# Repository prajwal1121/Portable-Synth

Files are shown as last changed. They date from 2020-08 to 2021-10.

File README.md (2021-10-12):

# Portable Synth
### An OP-1 inspired portable groovebox based around Teensy 4.1
Built using the awesome Teensy Audio Library
 
This project is still in progress, and will be for a while. Check back often for updates and bug fixes

**Current Status (1/13/2021)::white_check_mark:**

**Latest Updates (2/3/2021):** This code is outgrowing the Arduino IDE and I'm finally making the switch to VSCode and Platformio! This means the code will now and henceforth be organized in a more traditional C++ project structure rather than an awkward collections of .ino files. More importantly, the latest groovebox firmware has been reorganized into classes and multiple files in an effort to make it more modulualr and OOP-y. See README in Software folder for more information.

##### Check out the following links for development updates and more information about how to use the project files above
* Part 1 (Version 1): http://praj.tech/portfolio/portable-synth-v1-prototype/
* Part 2 (Version 1): http://praj.tech/portfolio/portable-synth-concept-design/
* Part 3 (Version 2): http://praj.tech/portfolio/porable-synth-hardware-upgrade/
* Part 4 (Version 2): http://praj.tech/portfolio/portable-synth-v2/

##### Or watch the demo videos here
###### V2
* Audio Recording and FM Radio: https://youtu.be/2ahzlKvuJ6E
* Build: https://youtu.be/Mdk-aUEtNno
* Sample Packs and Step Sequencer: https://youtu.be/XyqohSevqoo
* V2 Hardware and Synth with Mod Matrix: https://youtu.be/yj9AeDa9qw8

###### V1
* Endless Sequencer: https://youtu.be/U5Ci-TUZ0MY
* Recording and Sampling: https://youtu.be/KuPWz8McP5k
* Subtractive Synthesizer: https://youtu.be/QcZ3WIZ24l4

#### V2 - November 2020
Device Image

#### V1 Prototype - August 2020
Device Image

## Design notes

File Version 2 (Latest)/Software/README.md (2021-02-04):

## Project Code Files
The latest firmware can be found in the Groovebox_Platformio folder (a Platformio Project). Import it using Platformio into your editor of choice (I use VSCode). 

**A note for Platformio users:** Delete SDFat.h from *C:\Users\USERNAME\\.platformio\packages\framework-arduinoteensy\libraries\SD\utility* and instead install the latest version of the SDFat library through Platformio. This fixes a lot of problems. 

## Compiled Hex
If you don't actually want to see any of the code, just download the corresponding hex file, open it using Teensy Loader, and press the button on your Teensy to upload it!

## Older Code
Older code can be found in the Arduino Projects folder. These are all .ion files and can easily be opened and edited using the Arduino IDE.

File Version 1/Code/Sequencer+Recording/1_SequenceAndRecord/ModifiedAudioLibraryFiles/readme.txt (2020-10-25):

Replace the play_sd_raw.h and play_sd_raw.cpp files in your Teensy Audio Library directory with these files. 

They are identical except for the added ability to skip to a location in the audio file. See main sketch for usage example.

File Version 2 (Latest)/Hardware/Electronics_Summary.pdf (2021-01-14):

# V2.3 Electronics Summary

## Prajwal Tumkur Mahesh January 2020

# Schematics

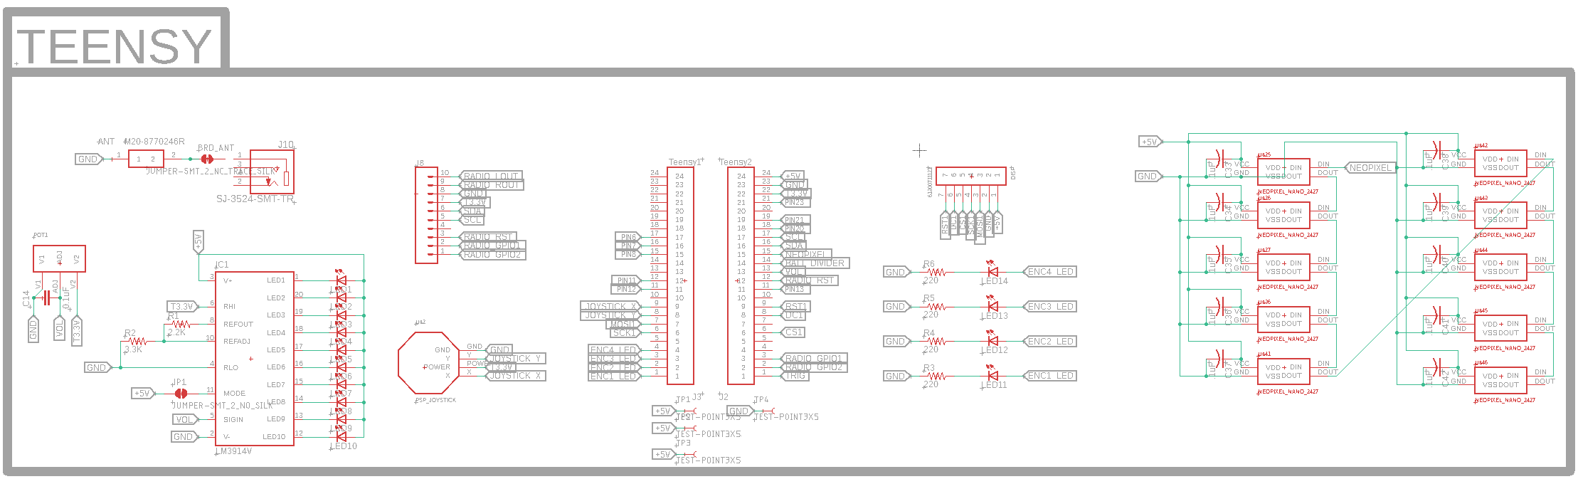
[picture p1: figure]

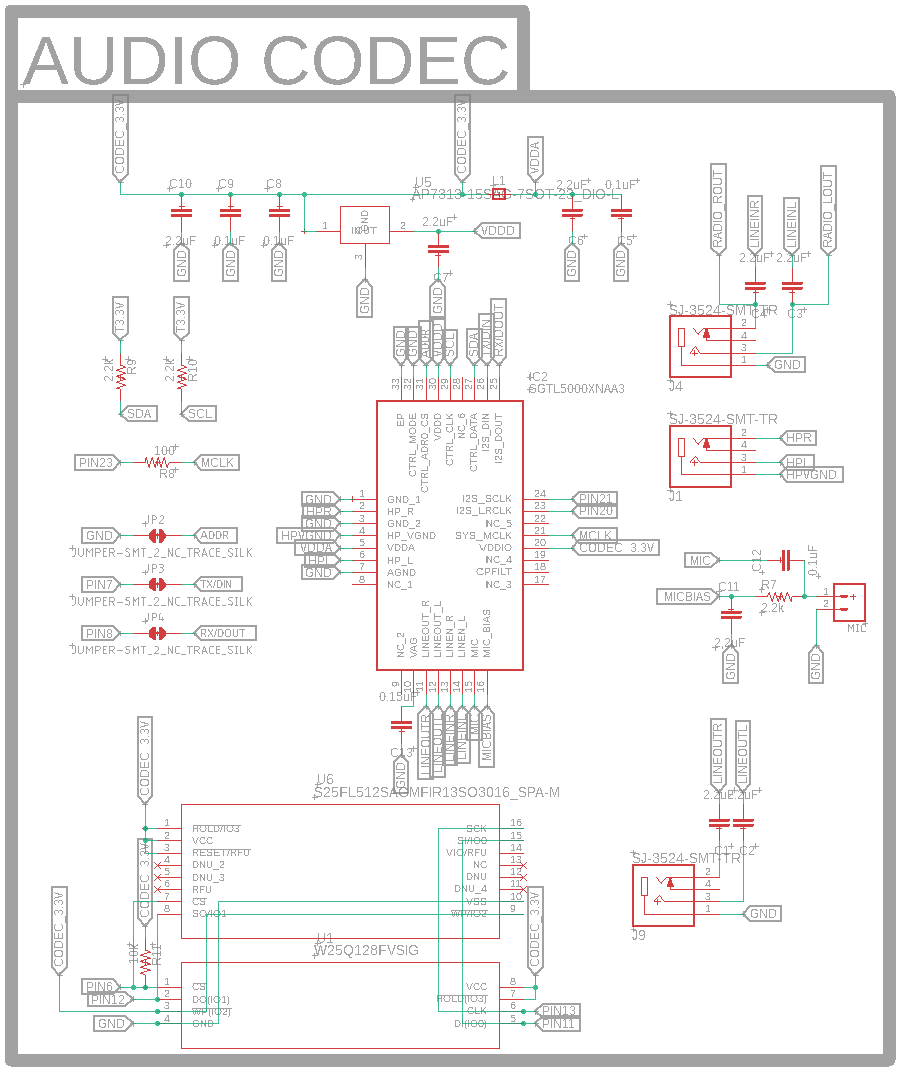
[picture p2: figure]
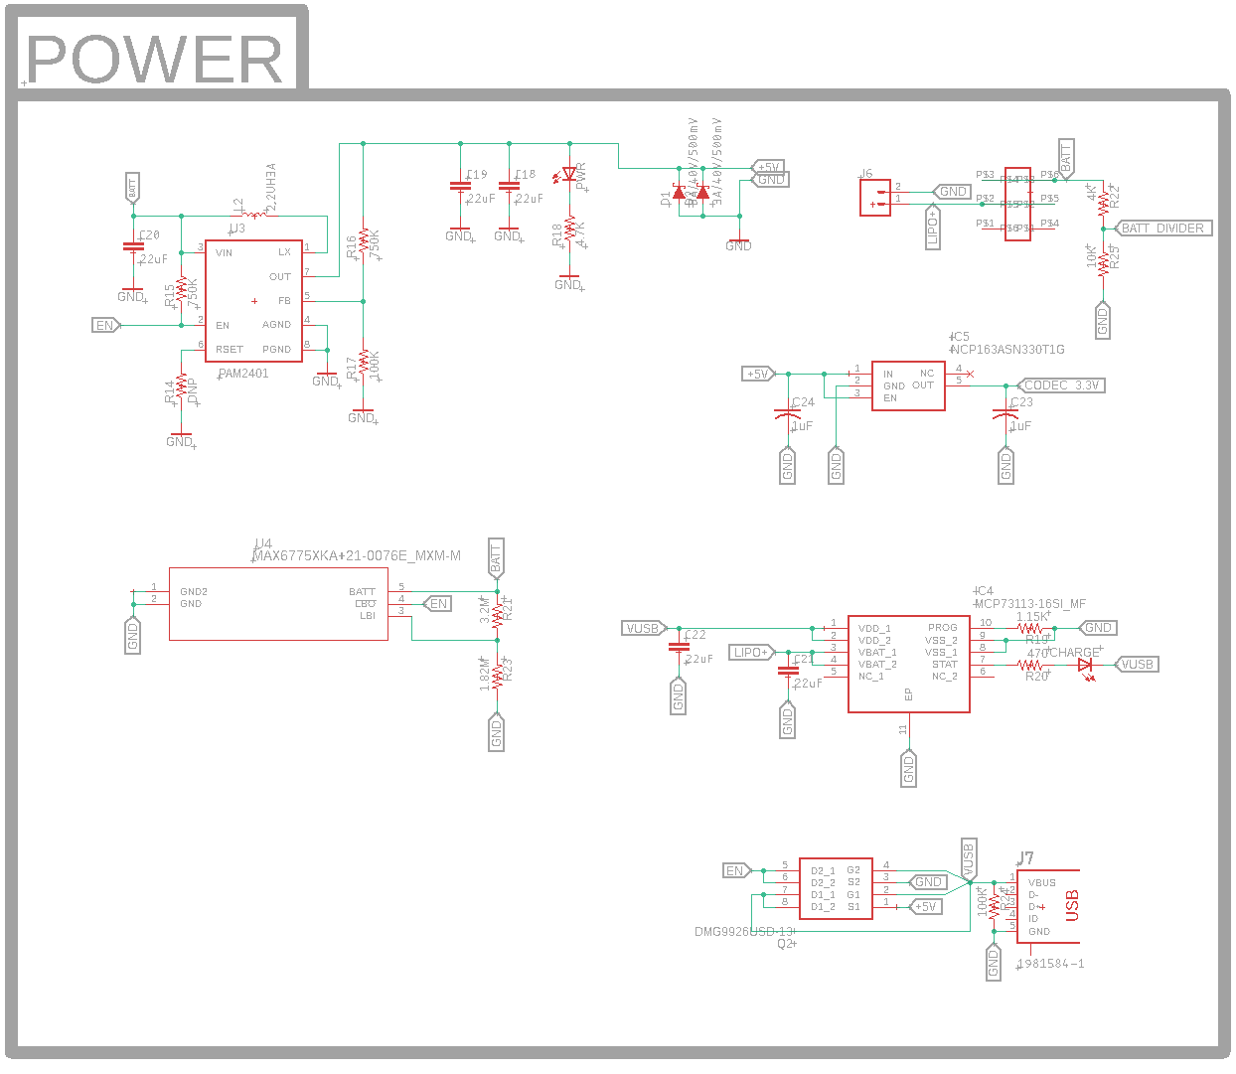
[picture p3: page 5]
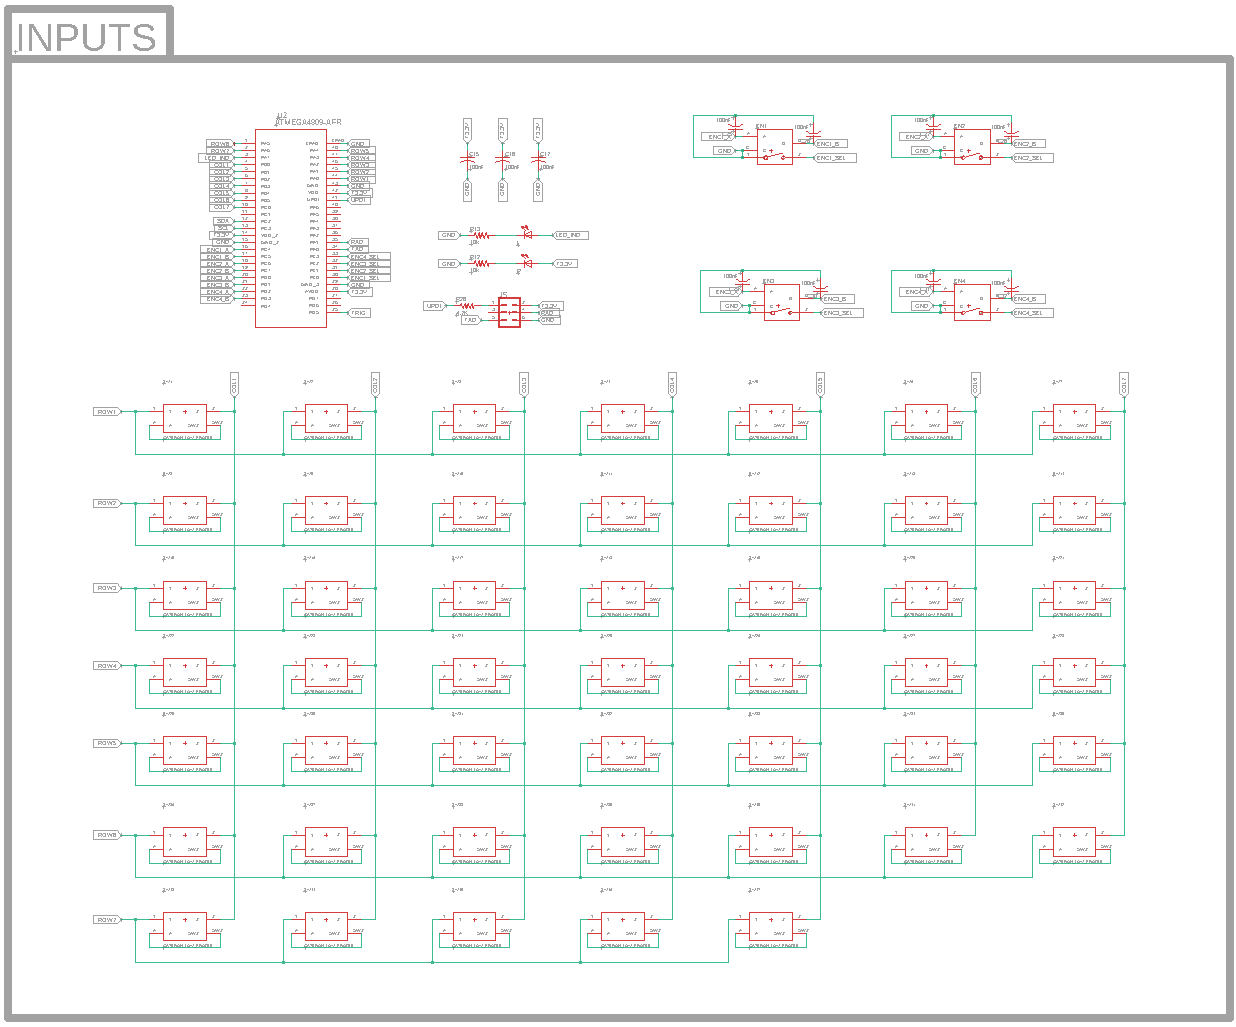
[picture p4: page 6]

# Board Layout

### FRONT:

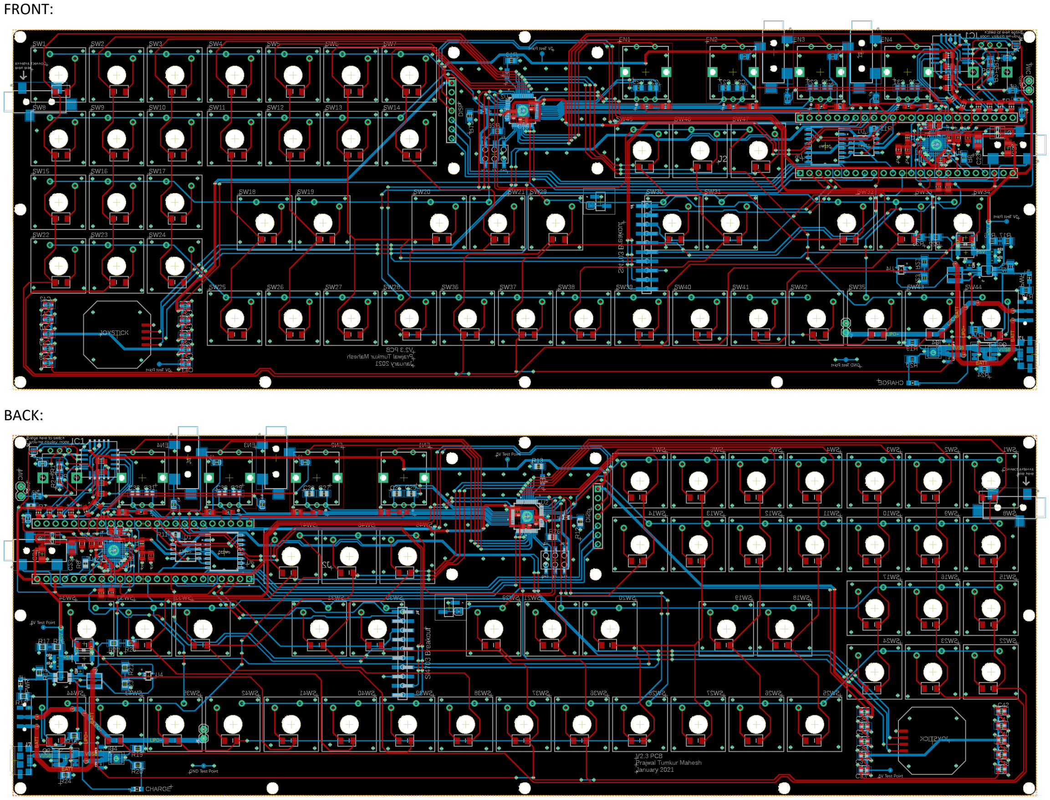
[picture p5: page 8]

### BACK:

# BOM

Manufacturer Part Number | Manufacturer | Digi-Key Part Number | Reference Designator | Quantity Unit Price Extended Price Description
CL21B225KPFNNNE | Samsung Electro-Mechanics | 1276-1188-1-ND | C1,C2,C3,C4,C6,C7,C10,C11 | 8 | 0.11 | $0.88 | CAP CER 2.2UF 10V X7R 0805
CL21B104KACNNNC | Samsung Electro-Mechanics | 1276-1099-1-ND | C5,C8,C9,C12,C14,C15,C16,C17,C25,C26,C27,C28,C29,
| | | C30,C31,C32,C33,C34,C35,C36,C37,C38,C39,C40,C41,C42 | 26 | 0.04 | $1.04 | CAP CER 0.1UF 25V X7R 0805
CL21B154KBFNNNG | Samsung Electro-Mechanics | 1276-6476-1-ND | C13 | 1 | 0.1 | $0.10 | CAP CER 0.15UF 50V X7R 0805
CL31B105KBHNFNE | Samsung Electro-Mechanics | 1276-3091-1-ND | C23,C24 | 2 | 0.15 | $0.30 | CAP CER 1UF 50V X7R 1206
3484 | Adafruit Industries LLC | 1528-2291-ND | | 1 | 4.95 | $4.95 | ADDRESS LED DISCRETE SERIAL RGB
LH R974-LP-1 | OSRAM Opto Semiconductors Inc. | 475-1415-1-ND | PWR,P,LED11 | 3 | 0.25 | $0.75 | LED RED DIFFUSED 0805 SMD
SML-LXT0805YW-TR | Lumex Opto/Components Inc. | 67-1554-1-ND | CHARGE,L,LED13 | 3 | 0.28 | $0.84 | LED YELLOW DIFFUSED SMD
QBLP631-IW | QT Brightek (QTB) | 1516-1085-1-ND | LED1,LED2,LED3,LED4,LED5,LED6,LED7,LED8,LED9,LED10 | 10 | 0.286 | $2.86 | LED WHITE 0805 SMD
LG R971-KN-1 | OSRAM Opto Semiconductors Inc. | 475-1410-1-ND | LED12 | 1 | 0.25 | $0.25 | LED GREEN DIFFUSED 0805 SMD
HSMR-C170 | Broadcom Limited | 516-1445-1-ND | LED14 | 1 | 0.8 | $0.80 | LED BLUE DIFFUSED CHIP SMD
PEC11R-4115F-S0018 | Bourns Inc. | PEC11R-4115F-S0018-ND | EN1,EN2,EN3,EN4 | 4 | 1.57 | $6.28 | ROTARY ENCODER MECHANICAL 18PPR
P0915N-FC15BR10K | TT Electronics/BI | 987-1649-ND | POT1 | 1 | 1.36 | $1.36 | POT 10K OHM 1/20W PLASTIC LINEAR
B340A-13-F | Diodes Incorporated | B340A-FDICT-ND | D1,D2 | 2 | 0.41 | $0.82 | DIODE SCHOTTKY 40V 3A SMA
SGTL5000XNAA3 | NXP USA Inc. | SGTL5000XNAA3-ND | IC2 | 1 | 3.37 | $3.37 | IC AUDIO CODEC STEREO 32-QFN
ATMEGA4809-AFR | Microchip Technology | ATMEGA4809-AFRCT-ND | U2 | 1 | 1.59 | $1.59 | IC MCU 8BIT 48KB FLASH 48TQFP
IFSC1515AHER2R2M01 | Vishay Dale | 541-1404-1-ND | L2 | 1 | 0.56 | $0.56 | FIXED IND 2.2UH 3A 45 MOHM SMD
742792040 | Würth Elektronik | 732-1620-1-ND | L1 | 1 | 0.22 | $0.22 | FERRITE BEAD 600 OHM 0805 1LN
RNCP0805FTD10K0 | Stackpole Electronics Inc | RNCP0805FTD10K0CT-ND | R11,R12,R13,R25 | 4 | 0.1 | $0.40 | RES 10K OHM 1% 1/4W 0805
ERA-6AEB104V | Panasonic Electronic Components | P100KDACT-ND | R17,R24 | 3 | 0.31 | $0.93 | RES 100K OHM 0.1% 1/8W 0805
ESR10EZPJ222 | Rohm Semiconductor | RHM2.2KKCT-ND | R1,R7,R9,R10 | 4 | 0.1 | $0.40 | RES SMD 2.2K OHM 5% 0.4W 0805
RC0805FR-07750KL | Yageo | 311-750KCRCT-ND | R15,R16 | 2 | 0.1 | $0.20 | RES SMD 750K OHM 1% 1/8W 0805
CRGCQ0805F3K3 | TE Connectivity Passive Product | A129755CT-ND | R2 | 2 | 0.1 | $0.20 | CRGCQ 0805 3K3 1%
RC0805JR-074K7L | Yageo | 311-4.7KARCT-ND | R18,R26 | 2 | 0.1 | $0.20 | RES SMD 4.7K OHM 5% 1/8W 0805
RC0805FR-071K15L | Yageo | 311-1.15KCRCT-ND | R19 | 1 | 0.1 | $0.10 | RES SMD 1.15K OHM 1% 1/8W 0805
CRCW08054K00FKTA | Vishay Dale | 541-CRCW08054K00FKTACT-ND | R22 | 1 | 0.13 | $0.13 | RES SMD 4K OHM 1% 1/8W 0805
JS202011JAQN | C&K | CKN10722CT-ND | | 1 | 0.58 | $0.58 | SWITCH SLIDE DPDT 300MA 6V
W25Q128JVSIQ TR | Winbond Electronics | W25Q128JVSIQCT-ND | U1 | 1 | 1.42 | $1.42 | IC FLASH 128MBIT SPI/QUAD 8SOIC
PAM2401SCADJ | Diodes Incorporated | PAM2401SCADJDICT-ND | U3 | 1 | 0.99 | $0.99 | IC REG BOOST ADJUSTABLE 1A 8MSOP
AP7313-15SAG-7 | Diodes Incorporated | AP7313-15SAG-7DICT-ND | U5 | 1 | 0.39 | $0.39 | IC REG LINEAR 1.5V 150MA SOT23-3
MCP73113-16SI/MF | Microchip Technology | MCP73113-16SI/MF-ND | IC4 | 1 | 1.12 | $1.12 | IC BATT CONTRL LI-ION 1CEL 10DFN
NCP163ASN330T1G | ON Semiconductor | NCP163ASN330T1GOSCT-ND | IC5 | 1 | 0.49 | $0.49 | LDO REG ULTRA-LOW NOISE & HIGH P
SJ-3524-SMT-TR | CUI Devices | CP-3524SJCT-ND | | 4 | 0.95 | $3.80 | CONN JACK STEREO 3.5MM SMD R/A
10118192-0001LF | Amphenol ICC (FCI) | 609-4613-1-ND | | 1 | 0.48 | $0.48 | CONN RCPT USB2.0 MICRO B SMD R/A
10129380-910001ALF | Amphenol ICC (FCI) | 609-10129380-910001ALFCT-ND | | 1 | 0.26 | $0.26 | CONN HEADER SMD 10POS 2.54MM
DM3CS-SF | Hirose Electric Co Ltd | HR1972CT-ND | | 1 | 1.43 | $1.43 | CONN MICRO SD CARD HINGED TYPE
MAX6775XKB+T | Maxim Integrated | MAX6775XKB+TCT-ND | U4 | 1 | 2.18 | $2.18 | IC BATT MON MULTI-CHEM 1C SC70-5
POM-5046P-C3310-R | PUI Audio, Inc. | 668-1677-ND | MIC | 1 | 1.69 | $1.69 | MIC COND ANALOG OMNI -46DB 6MM D
LL4148 | ON Semiconductor | LL4148FSCT-ND | | 50 | 0.068 | $3.40 | DIODE GEN PURP 100V 200MA SOD80
RC0805FR-073M16L | Yageo | 311-3.16MCRCT-ND | R21 | 1 | 0.1 | $0.10 | RES SMD 3.16M OHM 1% 1/8W 0805
CRCW08051M82FKEA | Vishay Dale | 541-1.82MCCT-ND | R23 | 1 | 0.1 | $0.10 | RES SMD 1.82M OHM 1% 1/8W 0805
LM3914VX/NOPB | Texas Instruments | LM3914VX/NOPBCT-ND | IC1 | 1 | 3.71 | $3.71 | IC DRVR DOT/BAR DISPLAY 20PLCC
CRGCQ0805F220R | TE Connectivity Passive Product | A129741CT-ND | R3,R4,R5,R6 | 10 | 0.044 | $0.44 | CRGCQ 0805 220R 1%
CRGCQ0805J100R | TE Connectivity Passive Product | A130128CT-ND | R8 | 1 | 0.1 | $0.10 | CRGCQ 0805 100R 5%
CRGCQ0805F470R | TE Connectivity Passive Product | A129745CT-ND | R20 | 1 | 0.1 | $0.10 | CRGCQ 0805 470R 1%
CL21A226MQQNNNE | Samsung Electro-Mechanics | 1276-1100-1-ND | C18,C19,C20,C21,C22 | 5 | 0.14 | $0.70 | CAP CER 22UF 6.3V X5R 0805
444 | Adafruit Industries LLC | 1528-444-ND | JOYSTICK | 1 | 3.5 | $3.50 | PSP 2-AXIS ANALOG THUMB JOYSTICK
S25FL512SAGMFIR13 | Cypress Semiconductor Corp | 428-S25FL512SAGMFIR13CT-ND | U6 | 1 | 7.72 | $7.72 | IC FLASH 512MBIT SPI/QUAD 16SOIC
22284245 | Molex | 900-0022284245-ND | | 2 | 1.41 | $2.82 | CONN HEADER VERT 24POS 2.54MM
61300711121 | Würth Elektronik | 732-5320-ND | | 1 | 0.37 | $0.37 | CONN HEADER VERT 7POS 2.54MM

# DIGIKEY

CART LINK: https://www.digikey.com/short/4734rh

ITEM | QUANTITY UNIT PRICE EXTENDED PRICE LINK
Low Profile Gateron Mechanical Switch Set | 4 | $4.00 | $16.00 | http://bit.ly/38GNrUU
ITEM | QUANTITY UNIT PRICE EXTENDED PRICE LINK
Waveshare 1.5inch RGB OLED Display Module | 4 | $18.90 | 18.9 | https://amzn.to/3qhuBcX
ITEM | QUANTITY UNIT PRICE EXTENDED PRICE LINK
Teensy 4.1 | 1 | $26.85 | $26.85 | http://bit.ly/3ibYI2y
PSRAM Chip | 2 | $1.20 | $2.40 | http://bit.ly/3nQR6nC

# KEYCHRON

# AMAZON

# PJRC

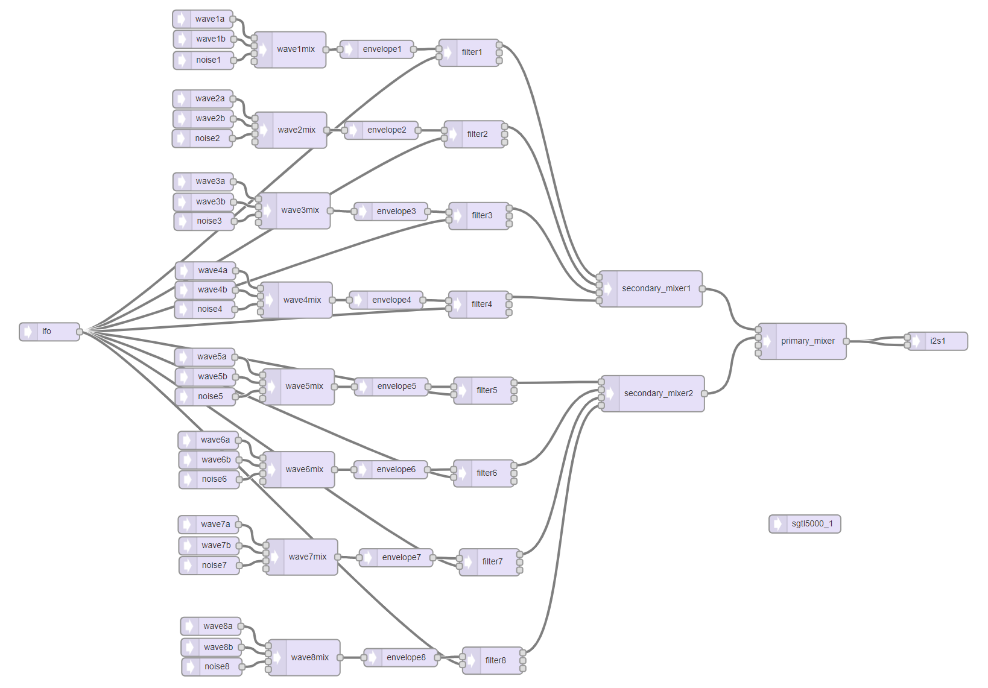
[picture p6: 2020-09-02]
Version 1/Code/Polyphonic Synthesizer/Full System.PNG

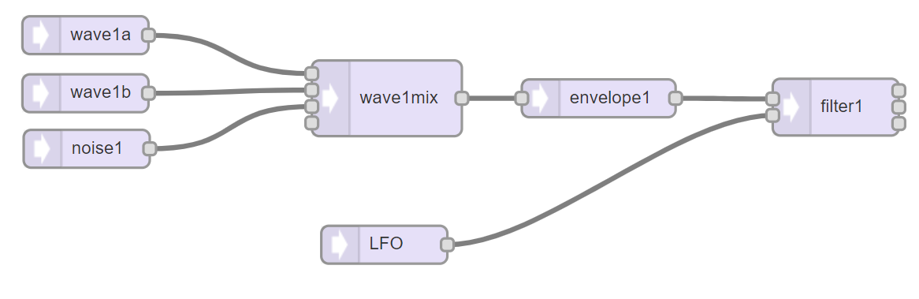
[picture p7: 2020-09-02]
Version 1/Code/Polyphonic Synthesizer/Single Voice.PNG

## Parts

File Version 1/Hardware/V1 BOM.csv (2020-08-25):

Manufacturer Part Number | Manufacturer | Digi-Key Part Number | Customer Reference | Reference Designator | Packaging | Part Status | Quantity | Unit Price | Extended Price | Quantity Available | Mfg Std Lead Time | Description | RoHS Status | Lead Free Status | REACH Status
C0805C104Z5VACTU | KEMET | 399-1177-1-ND |  |  | Cut Tape (CT) | Active | 20 | 0.05500 | $1.10 | 432470 | 8 Weeks | CAP CER 0.1UF 50V Y5V 0805 | ROHS3 Compliant | Lead free | REACH Unaffected
PMEG4005EJF | Nexperia USA Inc. | 1727-8451-1-ND |  |  | Cut Tape (CT) | Discontinued at Digi-Key | 2 | 0.32000 | $0.64 | 1819 | Not Available | PMEG4005EJ/SOD323/SOD2 | Not Available | Not Available | REACH Unaffected
PEC11R-4215F-S0024 | Bourns Inc. | PEC11R-4215F-S0024-ND |  |  | Tray | Active | 3 | 1.57000 | $4.71 | 3157 | 16 Weeks | ROTARY ENCODER MECHANICAL 24PPR | ROHS3 Compliant | Lead free | REACH Unaffected
LY R976-PS-36 | OSRAM Opto Semiconductors Inc. | 475-2560-1-ND |  |  | Cut Tape (CT) | Active | 2 | 0.28000 | $0.56 | 108282 | 12 Weeks | LED YELLOW DIFFUSED 0805 SMD | ROHS3 Compliant | Lead free | REACH Unaffected
LH R974-LP-1 | OSRAM Opto Semiconductors Inc. | 475-1415-1-ND |  |  | Cut Tape (CT) | Active | 2 | 0.26000 | $0.52 | 137407 | 12 Weeks | LED RED DIFFUSED 0805 SMD | ROHS3 Compliant | Lead free | REACH Unaffected
RNCP0805FTD10K0 | Stackpole Electronics Inc | RNCP0805FTD10K0CT-ND |  |  | Cut Tape (CT) | Active | 5 | 0.10000 | $0.50 | 434658 | 18 Weeks | RES 10K OHM 1% 1/4W 0805 | ROHS3 Compliant | Lead free | REACH Unaffected
3484 | Adafruit Industries LLC | 1528-2291-ND |  |  | Bulk | Active | 1 | 4.95000 | $4.95 | 662 | Not Available | ADDRESS LED DISCRETE SERIAL RGB | ROHS3 Compliant | Lead free | Not Available
JS202011JAQN | C&K | CKN10722CT-ND |  |  | Cut Tape (CT) | Active | 1 | 0.63000 | $0.63 | 28946 | 13 Weeks | SWITCH SLIDE DPDT 300MA 6V | ROHS3 Compliant | Lead free | REACH Unaffected
ATMEGA64L-8AU | Microchip Technology | ATMEGA64L-8AU-ND |  |  | Tray | Active | 1 | 7.79000 | $7.79 | 820 | 7 Weeks | IC MCU 8BIT 64KB FLASH 64TQFP | ROHS3 Compliant | Lead free | REACH Unaffected
TXS0102DCUR | Texas Instruments | 296-21931-1-ND |  |  | Cut Tape (CT) | Active | 1 | 0.69000 | $0.69 | 48140 | 6 Weeks | IC TRNSLTR BIDIRECTIONAL 8VSSOP | ROHS3 Compliant | Lead free | REACH Unaffected
CSTNE8M00G550000R0 | Murata Electronics | 490-17958-1-ND |  |  | Cut Tape (CT) | Active | 2 | 0.28000 | $0.56 | 42024 | 11 Weeks | CERAMIC RES 8.0000MHZ 33PF SMD | ROHS3 Compliant | Contains lead | Not Available
PTV09A-4020F-B203 | Bourns Inc. | PTV09A-4020F-B203-ND |  |  | Tray | Active | 1 | 0.83000 | $0.83 | 968 | 16 Weeks | POT 20K OHM 1/20W CARBON LINEAR | ROHS3 Compliant | Lead free | REACH Unaffected
SJ-3524-SMT-TR | CUI Devices | CP-3524SJCT-ND |  |  | Cut Tape (CT) | Active | 1 | 1.04000 | $1.04 | 125769 | 11 Weeks | CONN JACK STEREO 3.5MM SMD R/A | RoHS Compliant | Lead free | Not Available

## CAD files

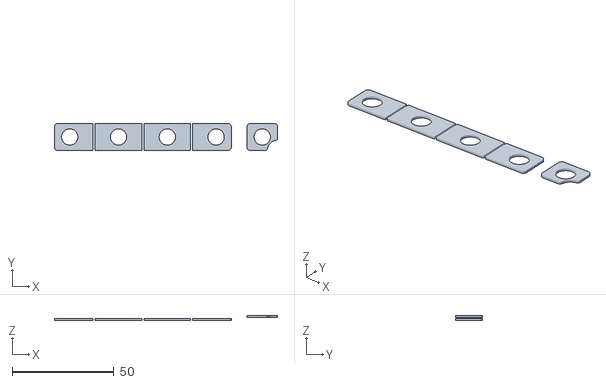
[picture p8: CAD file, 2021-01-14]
Version 2 (Latest)/Hardware/STL Files/EncoderCovers.stl
109.7 x 13.2 x 2.63

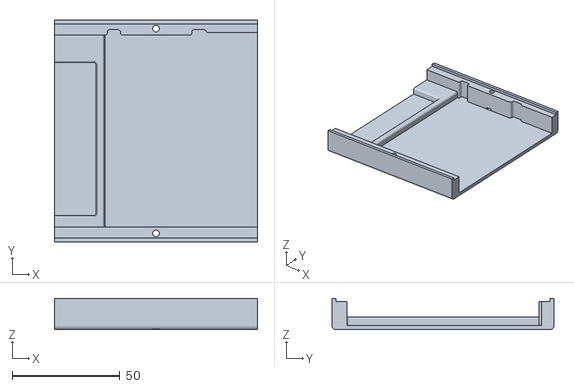
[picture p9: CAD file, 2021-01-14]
Version 2 (Latest)/Hardware/STL Files/Body2of3.stl
94.2 x 103.0 x 14.6

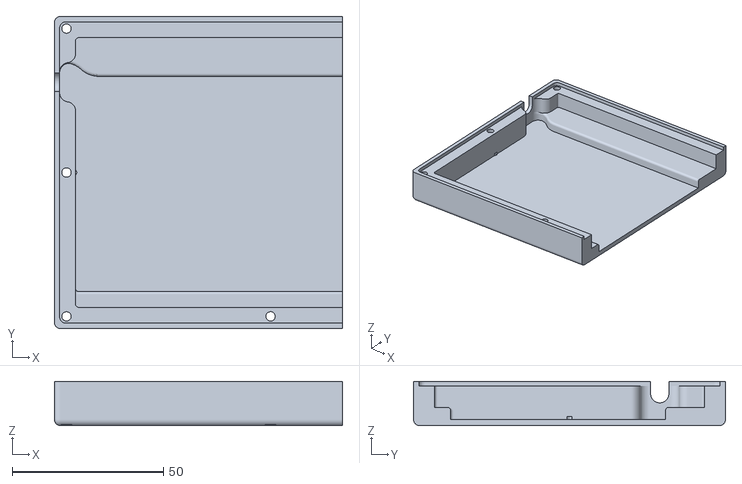
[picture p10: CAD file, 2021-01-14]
Version 2 (Latest)/Hardware/STL Files/Body1of3.stl
95.2 x 103.0 x 14.6

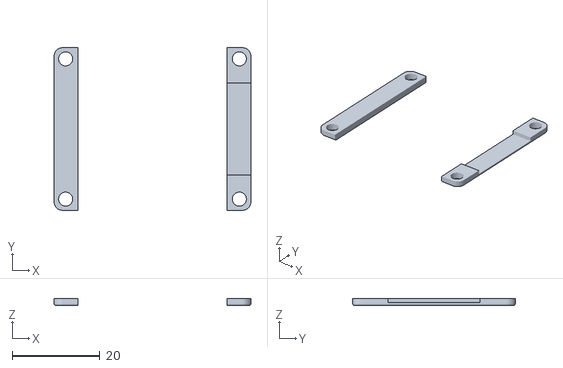
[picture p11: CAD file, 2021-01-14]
Version 2 (Latest)/Hardware/STL Files/DisplayCovers.stl
44.8 x 37.0 x 1.70

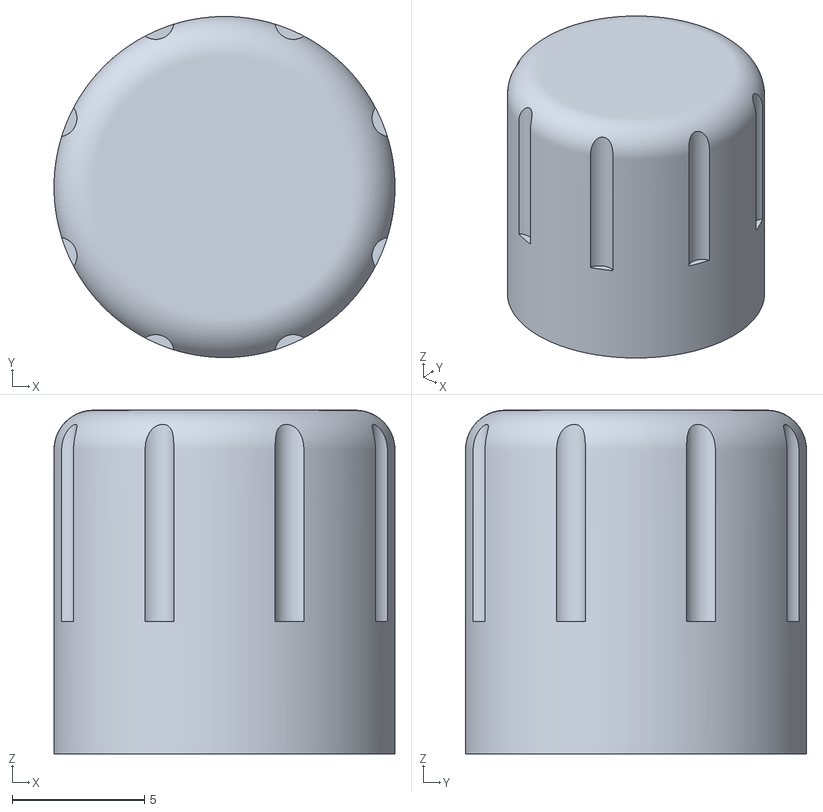
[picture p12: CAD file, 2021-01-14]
Version 2 (Latest)/Hardware/STL Files/Knob.stl
12.9 x 12.9 x 13.0

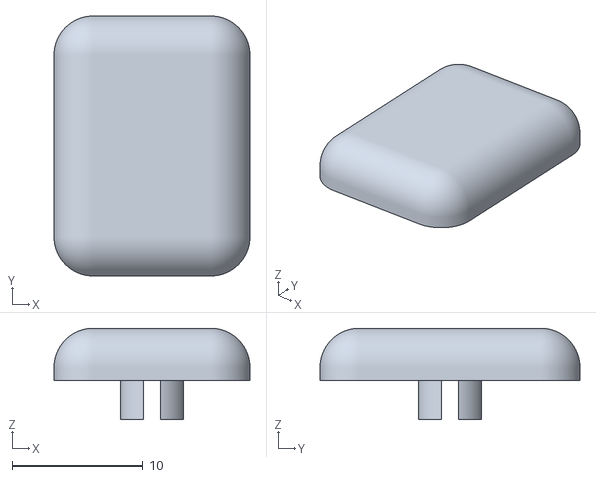
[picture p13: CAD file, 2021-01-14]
Version 2 (Latest)/Hardware/STL Files/MediumKey.stl
15.0 x 19.9 x 7.00

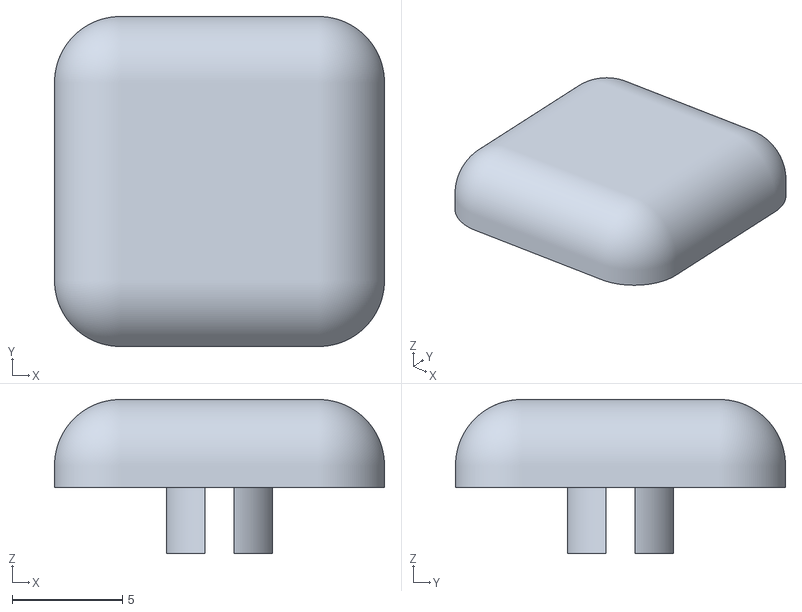
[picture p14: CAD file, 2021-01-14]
Version 2 (Latest)/Hardware/STL Files/SmallKey.stl
15.0 x 15.0 x 7.00

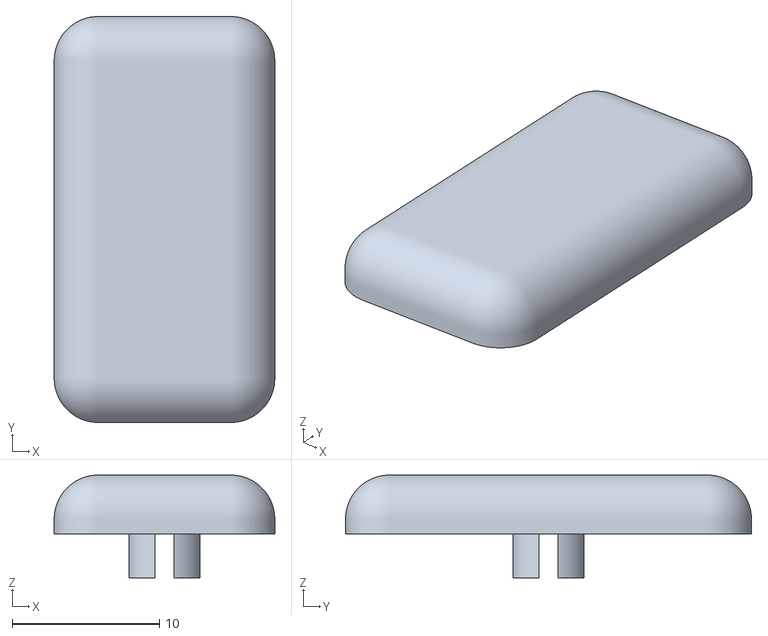
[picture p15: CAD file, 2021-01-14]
Version 2 (Latest)/Hardware/STL Files/BigKey.stl
15.0 x 27.6 x 7.00

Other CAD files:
Version 2 (Latest)/Hardware/STL Files/Body3of3.stl

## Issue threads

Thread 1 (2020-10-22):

Audio Quality and other comments

dackdel, 2020-10-22:
Do you have a sample track that you created purely on the portable-synth (will you be changing the name) uploaded in high quality (.wav or similar) here? Would be great to know what the teensy is capable of in terms of audio. This reminds me a lot of https://github.com/OTTO-project/OTTO OTTO and loosely reminds me of this guy in Madras who made (dinisnoise.org/) this, dinisnoise is software tho.

Are you planning on a bigger screen to have information be more descriptive with traditional synth like names/labels and or logos? Attaching some references
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

Great work!

prajwal1121, 2020-10-22:
Thanks for the comment! I will definitely be changing the name-I just haven't been inspired yet lol

I unfortunately don't have a sample track on here yet, but thanks for bringing that up- I'll try to record that at some point. I can tell you that the audio library is capable of CD quality audio (16bit 44.1kHz), and the Teensy 4 is more than capable of delivering on that (so far)

The OTTO project was a big inspiration for this! OTTO runs on an OS (linux) though, and with my project, I wanted to explore what was possible with a lower-level microcontroller-based implementation. Although tbh, the new Raspberry Pi 4 is looking like a pretty tempting choice

Thanks for the reference images. I'm definitely planning to add a bigger screen for cool graphics and a better UI for navigation and control. I'm glad you brought that up because this is pretty much at the top of my agenda for the next hardware version. It has been a little difficult though to choose a suitable screen. The display on the OP1 is a high-res (and apparently expensive) color OLED iirc, which is why it looks so spectacular, but I have no idea where to source something similar . I've also been trying to avoid LCDs, especially because most of the cheap ones have really ugly backlight bleed that ruins the look. So, for the moment I'm sticking with OLED displays for the sharpness and contrast but that obviously doesn't leave me with a lot of options. All of the OLED displays I can find (that can communicate to microcontrollers via SPI/I2C) have pretty low resolutions compared to their LCD counterparts, meaning I have 128x128 pixels or lower to work with. My current forerunner is this 1.5" RGB OLED display which is cheap enough at $20 for me to justify using: https://www.waveshare.com/wiki/1.5inch_RGB_OLED_Module

If you have any suggestions or recommendations for displays I should check out, including LCDs, I'd love to hear about it!

Also, as I mentioned, I'm currently working on updating the hardware and electronics - and the upgrade path is pretty open ended. If you can think of any hardware features you'd like to see, let me know!

dackdel, 2020-10-22:
a resource for screen related info https://github.com/juj/fbcp-ili9341
inspiration for hardware aesthetic https://rama.works/ and ofcourse teenage engineering and OTTO
if im not mistaken i think OTTO plan to use Startek KD028QVFMA017 source: https://www.instagram.com/p/CAKuK0cBTWE/?igshid=7xawm8s60enx
the images i attached are from the otto discord channel, i found out about you cause they are talking about you over there.

prajwal1121, 2020-10-22:
I appreciate the links, those'll be useful
Also, glad to hear I was mentioned on the OTTO discord 😄

dackdel, 2020-10-23:
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
https://github.com/OTTO-project/OTTO/issues/136

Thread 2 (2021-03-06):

R22/4k alternative

sepal, 2021-03-06:
Hi, thx for this awesome project!!
I'm wanna build one this synths myself, and I already got almost all components. The only trouble I have is with R22, the 4k ohm resistor. On digikey the resistor has currently lead time of 4 months and also other sites like mouser don't have any available.
Would a 4,02k Ohm resistor like this one also work? https://www.digikey.at/product-detail/de/yageo/RT0805BRD074K02L/YAG4909CT-ND/6617065
Sorry if this is a stupid question, but I can not tell what R22 is used for 🙈

prajwal1121, 2021-03-06:
Cool! I'm excited to hear you're building it!

Yep, 4.02K will work perfectly fine. And no worries, its not a stupid question haha- R22(4k) and R25(10k) together make up a voltage divider through which the Teensy can monitor the battery voltage, so that small of a change in one of the resistor values won't make a difference.

sepal, 2021-03-06:
awesome, thx for the quick reply!

Closed 2021-03-06.

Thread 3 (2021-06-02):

Future Changes

tagur87, 2021-06-02:
Hi Prajwal,

I am amazed at your incredible work on this, and appreciate so greatly that you provide all the code, stl, and cad files for those of us looking to follow your work and make their own.

What do you forsee in the future for this project? Do you see more software upgrades? Or more hardware changes?

I understand this is very much still a work in progress, but was wondering if you intend to make any more major hardware revisions in the future, or if you will mainly focus on software, that will improve on the current design.

Thanks for any insight you can provide!

Closed 2023-08-15.

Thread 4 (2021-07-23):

Experienced C++ Developer and OP-1 owner, How can I help?

acidtonic, 2021-07-23:
I have been dreaming of creating something like this for awhile now. I have an OP1 and wanted to develop my own software on it.

I am very interested in this project and I would love to help with the code. I'd have to first build a board which would be a bit challenging for me as I can solder, yet with the pins so close it makes me nervous I'd ruin something.

What are your current areas of interest with the software side? I'd be interested in helping write some midi/sequencer engines and such. I'm the principal developer for huge C++ projects for my day job and can help with organizing the project structure if desired.

I'm a percussionist, OP1 owner and I have a lot of odd musical ideas that would be cool for a groovebox like this...  Let's work together.

acidtonic, 2021-07-29:
I have a cad guy on staff and I snagged him after work to look at this.... we managed to open up the project in Kicad on linux. Got the autorouter setup and components loaded. Not sure if we need to submit this and make some boards or if we should just breadboard it out at this stage.

Ordered a few Teensy's and the required chips. Should be arriving tomorrow.

Still very interested in working with you. Let me know your thoughts.

acidtonic, 2021-08-09:
Soldered about 30 cherrymx keys to breakout boards, decided to use larger prototype boards for now since I don't nee the polished design. I found 10x22cm double-sided boards and will be combining various elements of your design along with mine into a much larger board for now.

I decided to order fancy audiophile DACs and amplifiers for mine, and optoisolated IO which will complicate the design a bit. I wanted to also introduce the idea of multiple "jacks" on the top of the board where different chips can be added or removed into color coded "slots". So similar to your idea where samples are loaded to flash with a small delay, I'd like to go farther and allow removing/mixing/matching different banks of flash chips to allow swapping samples in physical form.

I also wanted to go all in and provide 2 or 3 full-size 5pin MIDI jacks to my design since I'm planning to implement a MIDI looper with external/internal clock-sync and solo/hold-to-mute modes.

I am debating on whether to add a second Teensy 4.0 to offload the MIDI sequencing, such that internally the keys will actually be triggering MIDI on the first-teensy that the second (main) board will receive and operate purely off midi. This way I could turn off the second Teensy and only have a "dumb" midi controller/looper..... Then the main Teensy4.1 wouldn't need to do anything except handle MIDI input for the various synth engines I plan to add.

More stuff arriving tomorrow. Still hoping you respond and are working on this still.... :)

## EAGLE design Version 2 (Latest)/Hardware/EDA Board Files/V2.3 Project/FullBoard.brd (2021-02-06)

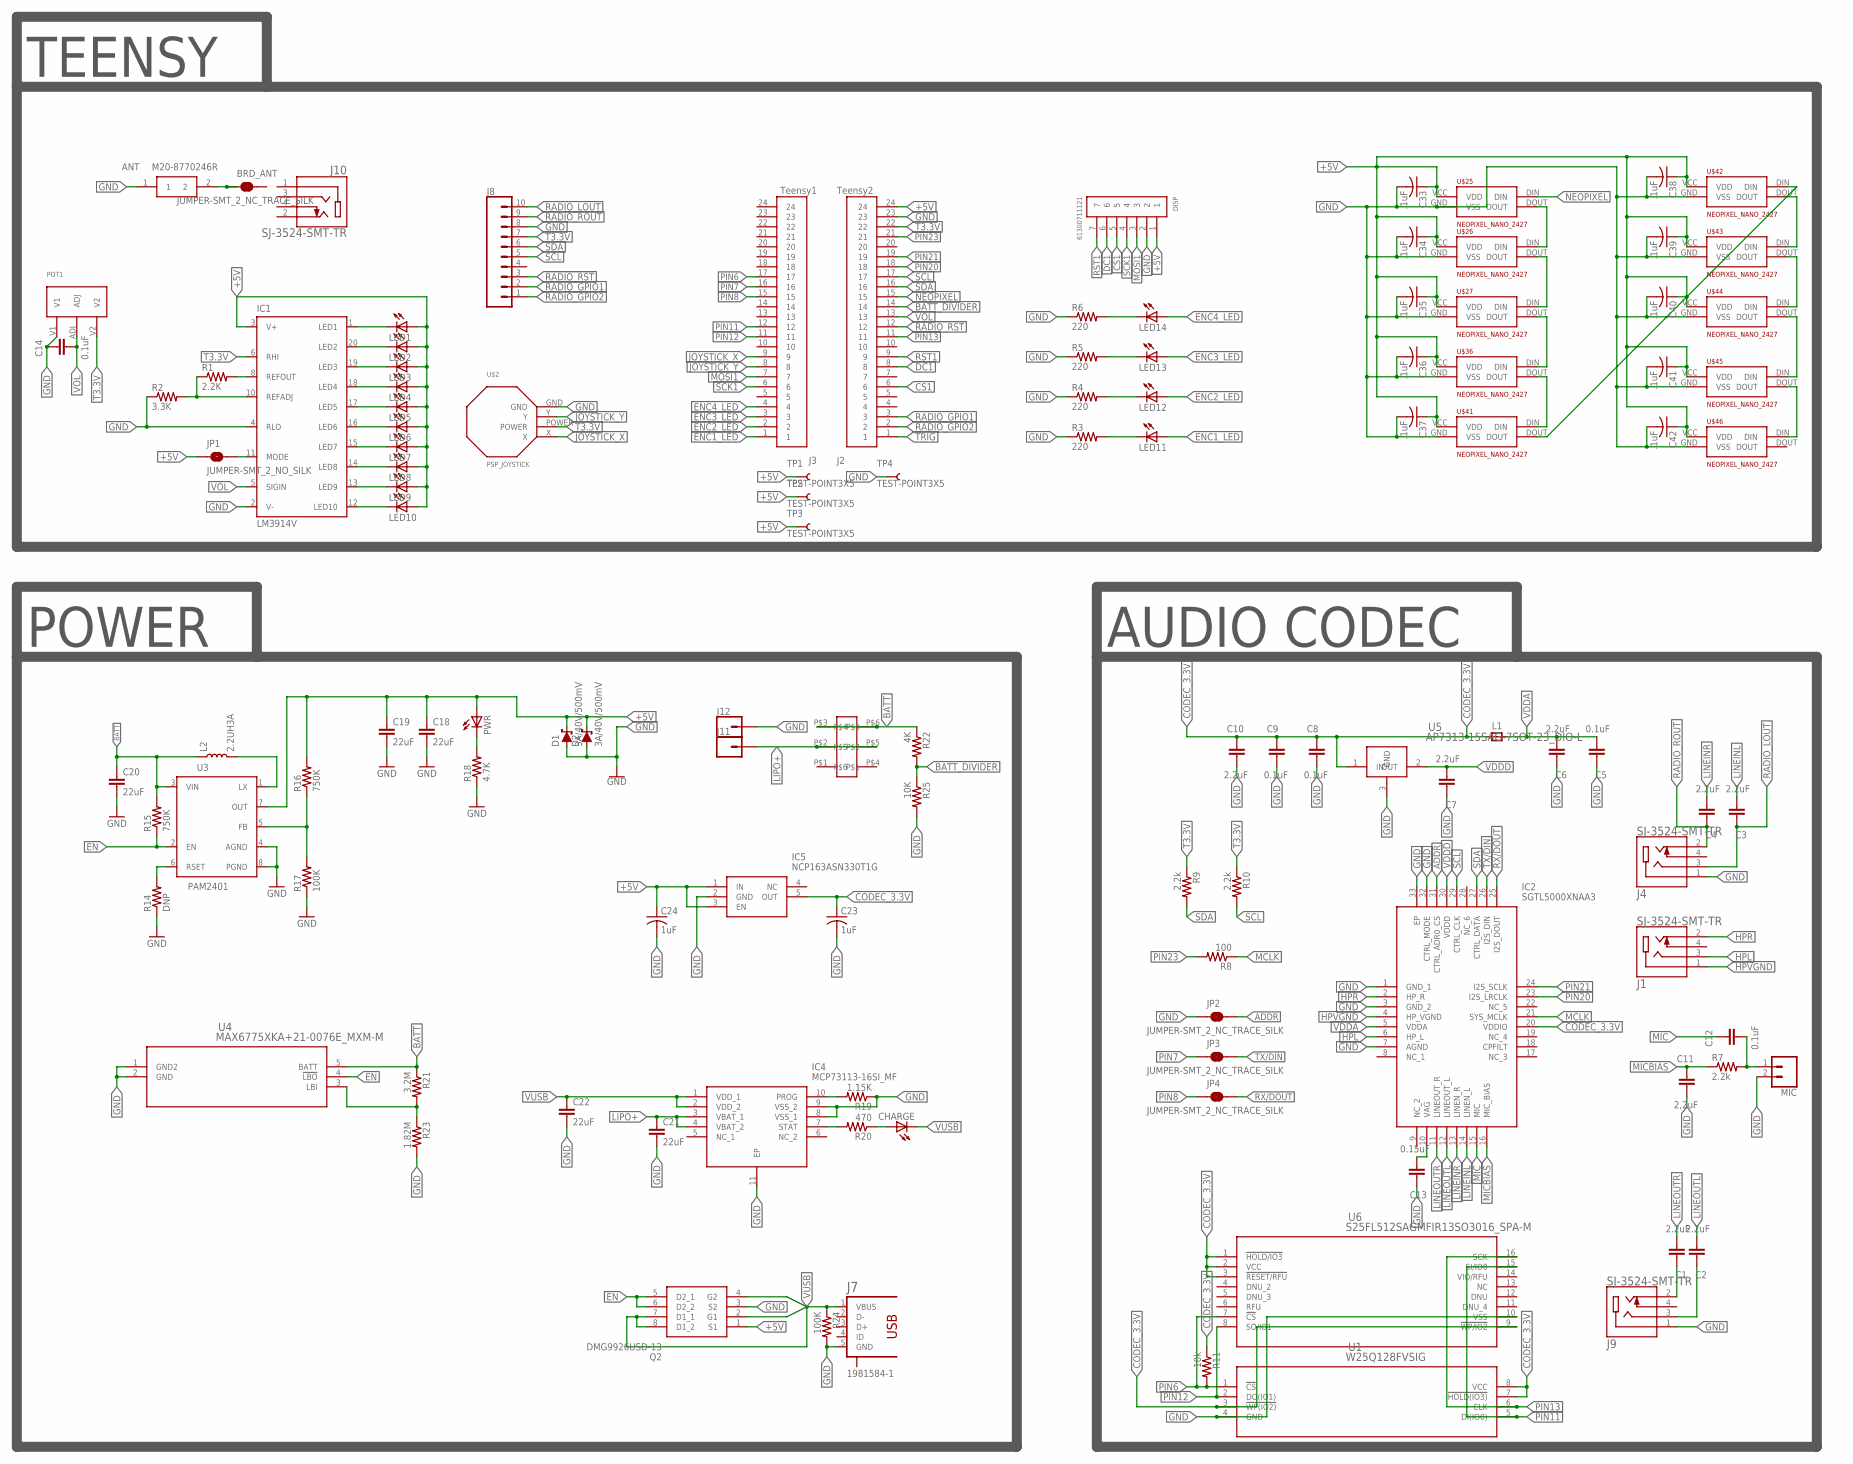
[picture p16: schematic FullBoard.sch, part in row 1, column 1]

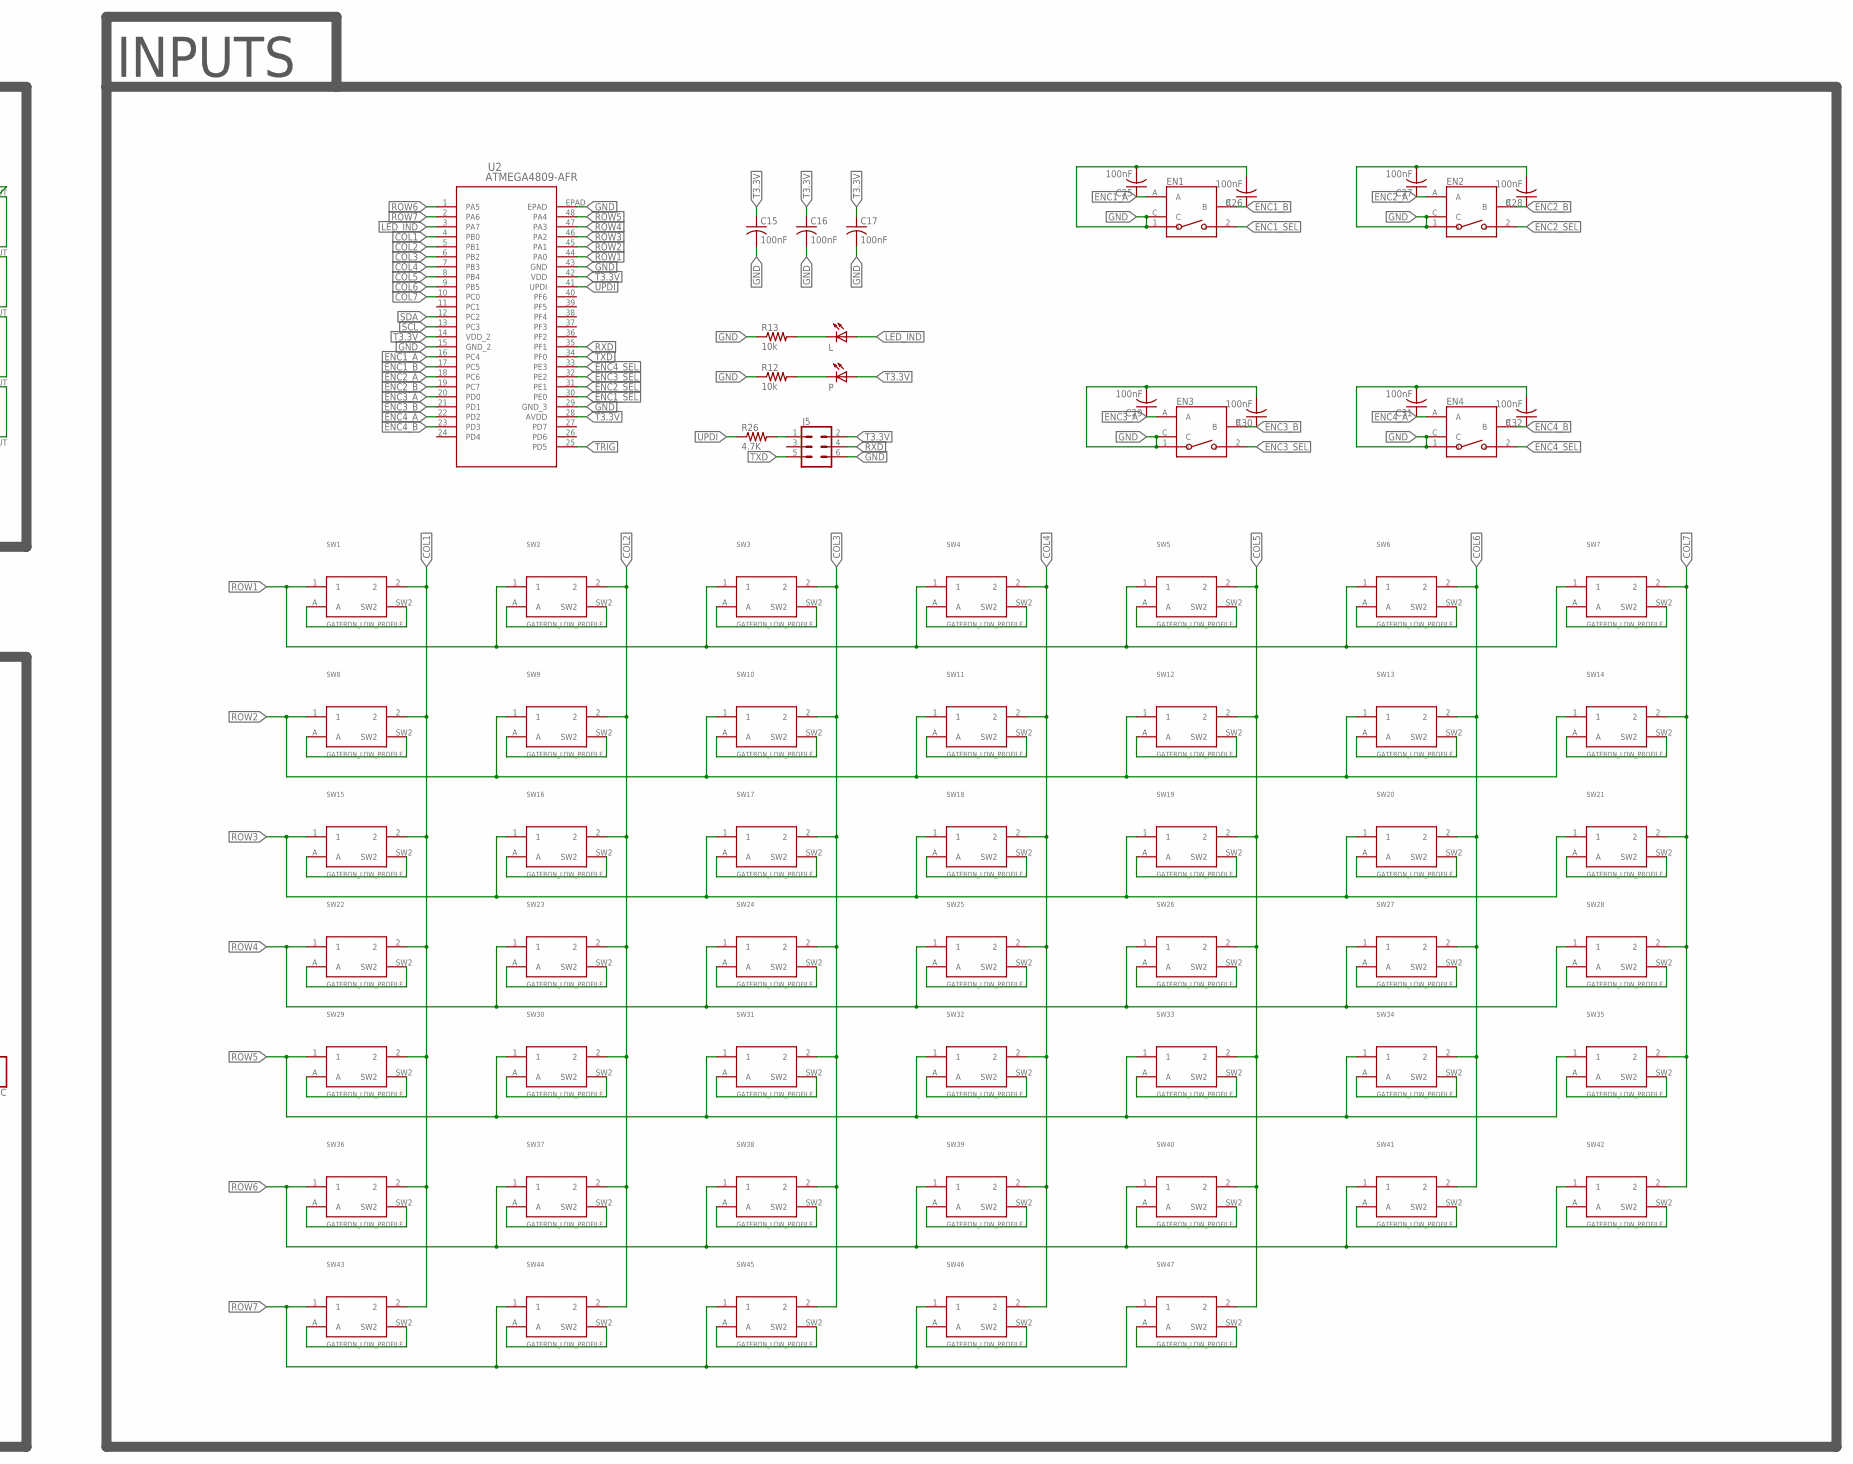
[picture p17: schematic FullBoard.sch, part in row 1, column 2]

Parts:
ANT: M20-8770246R; M208770246R
BRD_ANT: JUMPER-SMT_2_NC_TRACE_SILK; SMT-JUMPER_2_NC_TRACE_SILK
C1, C2, C3, C4, C6, C7, C10: 2.2uF; CAP_0805
C5, C8, C9, C12, C14: 0.1uF; CAP_0805
C11: 2,2uF; CAP_0805
C13: 0.15uF; CAP_0805
C15, C16, C17, C25, C26, C27, C28, C29, C30, C31, C32: 100nF; C0805
C18, C19, C20, C21, C22: 22uF; 0805
C23, C24: 1uF; C1206
C33, C34, C35, C36, C37, C38, C39, C40, C41, C42: .1uF; C0805
CHARGE: LEDCHIPLED_0805; CHIPLED_0805
D1, D2: 3A/40V/500mV; SMA-DIODE
DISP: 61300711121
EN1, EN2, EN3, EN4: PEC11R-4215K-S0024
IC1: LM3914V; PLCC20S
IC2: SGTL5000XNAA3; QFN50P500X500X90-33N
IC4: MCP73113-16SI_MF; SON50P300X300X100-11N
IC5: NCP163ASN330T1G; SOT95P280X145-5N
J1, J4, J9, J10: SJ-3524-SMT-TR
J2: Teensy2; 61302411121
J3: Teensy1; 61302411121
J5: CONN_03X2FEMALE_SMD; 2X3_SMD
J7: 1981584-1
J8: CONN_10SMD_MALE; 1X10_SMD_MALE
J11, J12: CONN_01; 1X01
JP1: JUMPER-SMT_2_NO_SILK; SMT-JUMPER_2_NO_SILK
JP2, JP3, JP4: JUMPER-SMT_2_NC_TRACE_SILK; SMT-JUMPER_2_NC_TRACE_SILK
L: LEDCHIPLED_0805; CHIPLED_0805
L1: RC-MASTER-SMD_FB_0805MP; RC-MASTER-SMD_L0805MP
L2: 2.2UH3A; INDUCTOR_4X4MM
LED1, LED2, LED3, LED4, LED5, LED6, LED7, LED8, LED9, LED10: LEDCHIP-LED0805; CHIP-LED0805
LED11, LED12, LED13, LED14: LEDCHIPLED_0805; CHIPLED_0805
MIC: CONN_02; 1X02
P: LEDCHIPLED_0805; CHIPLED_0805
POT1: P0915N_POT; PO915N_POT
PWR: LEDCHIPLED_0805; CHIPLED_0805
Q2: DMG9926USD-13; SOIC127P600X175-8N
R1: 2.2K; M0805
R2: 3.3K; M0805
R3, R4, R5, R6: 220; R0805
R7, R9, R10: 2.2k; R0805
R8: 100; R0805
R11, R12, R13: 10k; R0805
R14: DNP; M0805
R15, R16: 750K; M0805
R17, R24: 100K; M0805
R18: 4.7K; M0805
R19: 1.15K; M0805
R20: 470; M0805
R21: 3.2M; M0805
R22: 4K; M0805
R23: 1.82M; M0805
R25: 10K; M0805
R26: 4.7K; R0805
SW1, SW2, SW3, SW4, SW5, SW6, SW7, SW8, SW9, SW10, SW11, SW12, SW13, SW14, SW15, SW16, SW17, SW18, SW19, SW20, SW21, SW22, SW23, SW24, SW25, SW26, SW27, SW28, SW29, SW30, SW31, SW32, SW33, SW34, SW35, SW36, SW37, SW38, SW39, SW40, SW41, SW42, SW43, SW44, SW45, SW46, SW47: GATERON_LOW_PROFILE; GATERON_LP_PLAIN
TP1, TP2, TP3, TP4: TEST-POINT3X5; PAD.03X.05
U1: W25Q128FVSIG; WIN_S-8_WIN
U2: ATMEGA4809-AFR; TQFP48_7X7MC_MCH
U3: PAM2401; MSOP8
U4: MAX6775XKA+21-0076E_MXM-M; 21-0076E_MXM-M
U5: AP7313-15SAG-7SOT-23_DIO-L; SOT-23_DIO-L
U6: S25FL512SAGMFIR13SO3016_SPA-M; SO3016_SPA-M
U$1: JS202011JAQN
U$2: PSP_JOYSTICK
U$25, U$26, U$27, U$36, U$41, U$42, U$43, U$44, U$45, U$46: NEOPIXEL_NANO_2427; SK6805-2427

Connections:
!RADIO_RST: J2.12, J8.3
+5V: C18.1, C19.1, C24.1, C33.1, C34.1, C35.1, C36.1, C37.1, C38.1, C39.1, C40.1, C41.1, C42.1, D1.C, D2.C, DISP.1, IC1.3 (V+), IC5.1 (IN), IC5.3 (EN), J2.24, JP1.1, LED1.A, LED2.A, LED3.A, LED4.A, LED5.A, LED6.A, LED7.A, LED8.A, LED9.A, LED10.A, PWR.A, Q2.1 (S1), R16.2, TP1.P$1, TP2.P$1, TP3.P$1, U3.7 (OUT), U$25.VCC (VDD), U$26.VCC (VDD), U$27.VCC (VDD), U$36.VCC (VDD), U$41.VCC (VDD), U$42.VCC (VDD), U$43.VCC (VDD), U$44.VCC (VDD), U$45.VCC (VDD), U$46.VCC (VDD)
ADDR: IC2.31 (CTRL_ADR0_CS), JP2.2
BATT: C20.1, L2.P$1 (1), R15.2, R21.1, R22.1, U3.3 (VIN), U4.5 (BATT), U$1.P$3, U$1.P$6
BATT_DIVIDER: J2.14, R22.2, R25.1
CODEC_3.3V: C8.1, C9.1, C10.1, C23.1, IC2.20 (VDDIO), IC5.5 (OUT), L1.1, R11.1, U1.3 (!WP(IO2)), U1.7 (!HOLD(IO3)), U1.8 (VCC), U5.1 (IN), U6.1 (!HOLD/IO3), U6.2 (VCC), U6.3 (!RESET/RFU), U6.9 (!WP/IO2)
COL1: SW1.2, SW8.2, SW15.2, SW22.2, SW29.2, SW36.2, SW43.2, U2.4 (PB0)
COL2: SW2.2, SW9.2, SW16.2, SW23.2, SW30.2, SW37.2, SW44.2, U2.5 (PB1)
COL3: SW3.2, SW10.2, SW17.2, SW24.2, SW31.2, SW38.2, SW45.2, U2.6 (PB2)
COL4: SW4.2, SW11.2, SW18.2, SW25.2, SW32.2, SW39.2, SW46.2, U2.7 (PB3)
COL5: SW5.2, SW12.2, SW19.2, SW26.2, SW33.2, SW40.2, SW47.2, U2.8 (PB4)
COL6: SW6.2, SW13.2, SW20.2, SW27.2, SW34.2, SW41.2, U2.9 (PB5)
COL7: SW7.2, SW14.2, SW21.2, SW28.2, SW35.2, SW42.2, U2.10 (PC0)
CS1: DISP.5, J2.6
DC1: DISP.6, J2.8
EN: Q2.5 (D2_1), Q2.6 (D2_2), R15.1, U3.2 (EN), U4.4 (!LBO)
ENC1_A: C25.1, EN1.A, U2.16 (PC4)
ENC1_B: C26.1, EN1.B, U2.17 (PC5)
ENC1_LED: J3.1, LED11.A
ENC1_SEL: EN1.2, U2.30 (PE0)
ENC2_A: C27.1, EN2.A, U2.18 (PC6)
ENC2_B: C28.1, EN2.B, U2.19 (PC7)
ENC2_LED: J3.2, LED12.A
ENC2_SEL: EN2.2, U2.31 (PE1)
ENC3_A: C29.1, EN3.A, U2.20 (PD0)
ENC3_B: C30.1, EN3.B, U2.21 (PD1)
ENC3_LED: J3.3, LED13.A
ENC3_SEL: EN3.2, U2.32 (PE2)
ENC4_A: C31.1, EN4.A, U2.22 (PD2)
ENC4_B: C32.1, EN4.B, U2.23 (PD3)
ENC4_LED: J3.4, LED14.A
ENC4_SEL: EN4.2, U2.33 (PE3)
GND: ANT.1, C5.1, C6.1, C7.1, C8.2, C9.2, C10.2, C11.2, C13.1, C14.1, C15.2, C16.2, C17.2, C18.2, C19.2, C20.2, C21.2, C22.2, C23.2, C24.2, C25.2, C26.2, C27.2, C28.2, C29.2, C30.2, C31.2, C32.2, C33.2, C34.2, C35.2, C36.2, C37.2, C38.2, C39.2, C40.2, C41.2, C42.2, D1.A, D2.A, DISP.2, EN1.1, EN1.C, EN2.1, EN2.C, EN3.1, EN3.C, EN4.1, EN4.C, IC1.2 (V-), IC1.4 (RLO), IC2.1 (GND_1), IC2.3 (GND_2), IC2.7 (AGND), IC2.32 (CTRL_MODE), IC2.33 (EP), IC4.8 (VSS_1), IC4.9 (VSS_2), IC4.11 (EP), IC5.2 (GND), J2.23, J4.1, J5.6, J7.5 (GND), J8.8, J9.1, J12.1, JP2.1, MIC.2, POT1.V1, Q2.3 (S2), R2.1, R3.1, R4.1, R5.1, R6.1, R12.1, R13.1, R14.1, R17.1, R18.1, R19.1, R23.2, R24.2, R25.2, TP4.P$1, U1.4 (GND), U2.15 (GND_2), U2.29 (GND_3), U2.43 (GND), U2.EPAD, U3.4 (AGND), U3.8 (PGND), U4.1 (GND2), U4.2 (GND), U5.3 (GND), U6.10 (VSS), U$2.GND, U$25.GND (VSS), U$26.GND (VSS), U$27.GND (VSS), U$36.GND (VSS), U$41.GND (VSS), U$42.GND (VSS), U$43.GND (VSS), U$44.GND (VSS), U$45.GND (VSS), U$46.GND (VSS)
HPL: IC2.6 (HP_L), J1.3
HPR: IC2.2 (HP_R), J1.2
HPVGND: IC2.4 (HP_VGND), J1.1
JOYSTICK_X: J3.9, U$2.X
JOYSTICK_Y: J3.8, U$2.Y
LED_IND: L.A, U2.3 (PA7)
LINEINL: C3.2, IC2.14 (LINEN_L)
LINEINR: C4.2, IC2.13 (LINEN_R)
LINEOUTL: C2.2, IC2.12 (LINEOUT_L)
LINEOUTR: C1.2, IC2.11 (LINEOUT_R)
LIPO+: C21.1, IC4.3 (VBAT_1), IC4.4 (VBAT_2), J11.1, U$1.P$2, U$1.P$5
MCLK: IC2.21 (SYS_MCLK), R8.1
MIC: C12.1, IC2.15 (MIC)
MICBIAS: C11.1, IC2.16 (MIC_BIAS), R7.1
MOSI1: DISP.3, J3.7
unnamed: IC1.18 (LED4), LED4.C
unnamed: IC1.1 (LED1), LED1.C
unnamed: IC1.20 (LED2), LED2.C
unnamed: IC1.19 (LED3), LED3.C
unnamed: SW1.A, SW1.SW2
unnamed: IC1.17 (LED5), LED5.C
unnamed: IC1.16 (LED6), LED6.C
unnamed: IC1.15 (LED7), LED7.C
unnamed: IC1.14 (LED8), LED8.C
unnamed: IC1.13 (LED9), LED9.C
unnamed: IC1.12 (LED10), LED10.C
unnamed: IC1.10 (REFADJ), R1.1, R2.2
unnamed: IC1.11 (MODE), JP1.2
unnamed: IC1.8 (REFOUT), R1.2
unnamed: LED12.C, R4.2
unnamed: LED14.C, R6.2
unnamed: LED13.C, R5.2
unnamed: C13.2, IC2.10 (VAG)
unnamed: C12.2, MIC.1, R7.2
unnamed: C1.1, J9.2
unnamed: C2.1, J9.3
unnamed: SW2.A, SW2.SW2
unnamed: SW3.A, SW3.SW2
unnamed: SW4.A, SW4.SW2
unnamed: SW5.A, SW5.SW2
unnamed: SW6.A, SW6.SW2
unnamed: SW7.A, SW7.SW2
unnamed: SW8.A, SW8.SW2
unnamed: SW9.A, SW9.SW2
unnamed: SW10.A, SW10.SW2
unnamed: SW11.A, SW11.SW2
unnamed: SW12.A, SW12.SW2
unnamed: SW13.A, SW13.SW2
unnamed: SW14.A, SW14.SW2
unnamed: SW15.A, SW15.SW2
unnamed: SW16.A, SW16.SW2
unnamed: SW17.A, SW17.SW2
unnamed: SW18.A, SW18.SW2
unnamed: SW19.A, SW19.SW2
unnamed: SW20.A, SW20.SW2
unnamed: SW21.A, SW21.SW2
unnamed: SW22.A, SW22.SW2
unnamed: SW23.A, SW23.SW2
unnamed: SW24.A, SW24.SW2
unnamed: SW25.A, SW25.SW2
unnamed: SW26.A, SW26.SW2
unnamed: SW27.A, SW27.SW2
unnamed: SW28.A, SW28.SW2
unnamed: SW29.A, SW29.SW2
unnamed: SW30.A, SW30.SW2
unnamed: SW31.A, SW31.SW2
unnamed: SW32.A, SW32.SW2
unnamed: SW33.A, SW33.SW2
unnamed: SW34.A, SW34.SW2
unnamed: SW35.A, SW35.SW2
unnamed: SW36.A, SW36.SW2
unnamed: SW37.A, SW37.SW2
unnamed: SW38.A, SW38.SW2
unnamed: SW39.A, SW39.SW2
unnamed: SW40.A, SW40.SW2
unnamed: SW41.A, SW41.SW2
unnamed: SW42.A, SW42.SW2
unnamed: SW43.A, SW43.SW2
unnamed: SW44.A, SW44.SW2
unnamed: SW45.A, SW45.SW2
unnamed: SW46.A, SW46.SW2
unnamed: SW47.A, SW47.SW2
unnamed: L.C, R13.2
unnamed: P.C, R12.2
unnamed: LED11.C, R3.2
unnamed: R16.1, R17.2, U3.5 (FB)
unnamed: L2.P$2 (2), U3.1 (LX)
unnamed: R14.2, U3.6 (RSET)
unnamed: PWR.C, R18.2
unnamed: IC4.10 (PROG), R19.2
unnamed: IC4.7 (STAT), R20.2
unnamed: CHARGE.A, R20.1
unnamed: R21.2, R23.1, U4.3 (LBI)
unnamed: U$25.DOUT, U$26.DIN
unnamed: U$26.DOUT, U$27.DIN
unnamed: U$27.DOUT, U$36.DIN
unnamed: U$36.DOUT, U$41.DIN
unnamed: U$41.DOUT, U$42.DIN
unnamed: U$42.DOUT, U$43.DIN
unnamed: U$43.DOUT, U$44.DIN
unnamed: U$44.DOUT, U$45.DIN
unnamed: U$45.DOUT, U$46.DIN
unnamed: ANT.2, BRD_ANT.1
unnamed: J5.1, R26.2
NEOPIXEL: J2.15, U$25.DIN
PIN6: J3.17, R11.2, U1.1 (!CS), U6.7 (!CS)
PIN7: J3.16, JP3.1
PIN8: J3.15, JP4.1
PIN11: J3.12, U1.5 (DI(IO0)), U6.15 (SI/IO0)
PIN12: J3.11, U1.2 (DO(IO1)), U6.8 (SO/IO1)
PIN13: J2.11, U1.6 (CLK), U6.16 (SCK)
PIN20: IC2.23 (I2S_LRCLK), J2.18
PIN21: IC2.24 (I2S_SCLK), J2.19
PIN23: J2.21, R8.2
RADIO_GPIO1: J2.3, J8.2
RADIO_GPIO2: J2.2, J8.1
RADIO_LOUT: C3.1, J4.3, J8.10
RADIO_ROUT: C4.1, J4.2, J8.9
ROW1: SW1.1, SW2.1, SW3.1, SW4.1, SW5.1, SW6.1, SW7.1, U2.44 (PA0)
ROW2: SW8.1, SW9.1, SW10.1, SW11.1, SW12.1, SW13.1, SW14.1, U2.45 (PA1)
ROW3: SW15.1, SW16.1, SW17.1, SW18.1, SW19.1, SW20.1, SW21.1, U2.46 (PA2)
ROW4: SW22.1, SW23.1, SW24.1, SW25.1, SW26.1, SW27.1, SW28.1, U2.47 (PA3)
ROW5: SW29.1, SW30.1, SW31.1, SW32.1, SW33.1, SW34.1, SW35.1, U2.48 (PA4)
ROW6: SW36.1, SW37.1, SW38.1, SW39.1, SW40.1, SW41.1, SW42.1, U2.1 (PA5)
ROW7: SW43.1, SW44.1, SW45.1, SW46.1, SW47.1, U2.2 (PA6)
RST1: DISP.7, J2.9
RX/DOUT: IC2.25 (I2S_DOUT), JP4.2
RXD: J5.4, U2.35 (PF1)
SCK1: DISP.4, J3.6
SCL: IC2.29 (CTRL_CLK), J2.17, J8.5, R10.2, U2.13 (PC3)
SDA: IC2.27 (CTRL_DATA), J2.16, J8.6, R9.2, U2.12 (PC2)
T3.3V: C15.1, C16.1, C17.1, IC1.6 (RHI), J2.22, J5.2, J8.7, P.A, POT1.V2, R9.1, R10.1, U2.14 (VDD_2), U2.28 (AVDD), U2.42 (VDD), U$2.POWER
TRIG: J2.1, U2.25 (PD5)
TX/DIN: IC2.26 (I2S_DIN), JP3.2
TXD: J5.5, U2.34 (PF0)
UPDI: R26.1, U2.41 (UPDI)
VDDA: C5.2, C6.2, IC2.5 (VDDA), L1.2
VDDD: C7.2, IC2.30 (VDDD), U5.2 (OUT)
VOL: C14.2, IC1.5 (SIGIN), J2.13, POT1.ADJ
VUSB: C22.1, CHARGE.C, IC4.1 (VDD_1), IC4.2 (VDD_2), J7.1 (VBUS), Q2.2 (G1), Q2.4 (G2), Q2.7 (D1_1), Q2.8 (D1_2), R24.1

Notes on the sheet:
POWER
AUDIO CODEC
TEENSY
INPUTS

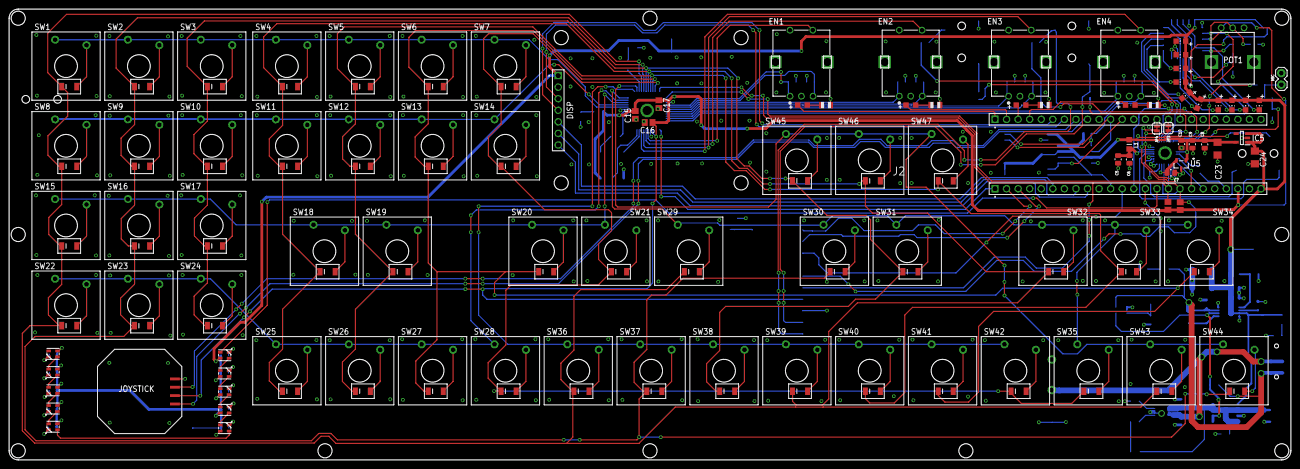
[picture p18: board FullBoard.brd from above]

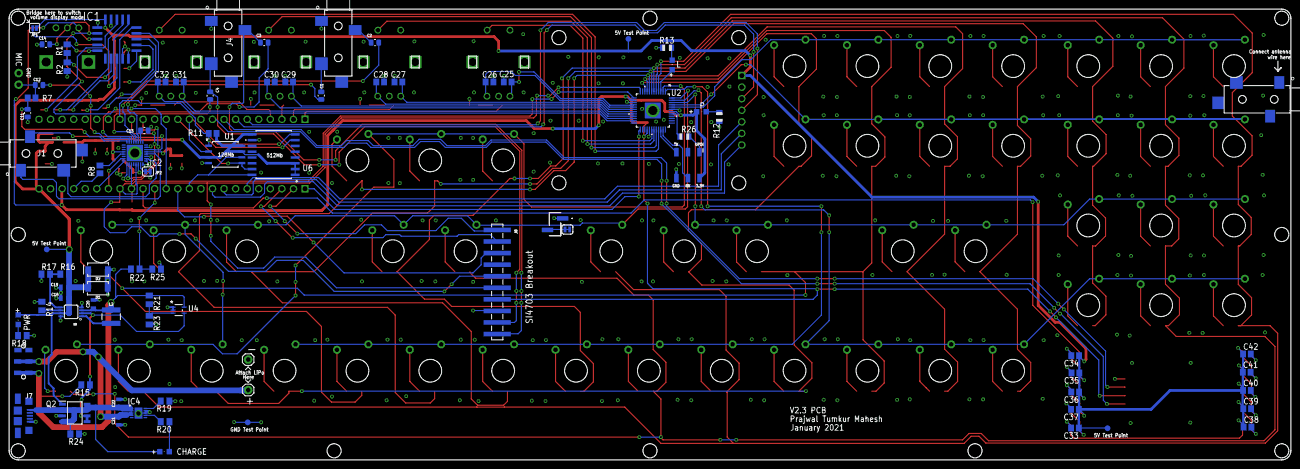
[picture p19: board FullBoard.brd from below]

Board: 4 copper layers, 281.5 x 99.0 mm, 188 parts (85 on the bottom side), 173 nets.

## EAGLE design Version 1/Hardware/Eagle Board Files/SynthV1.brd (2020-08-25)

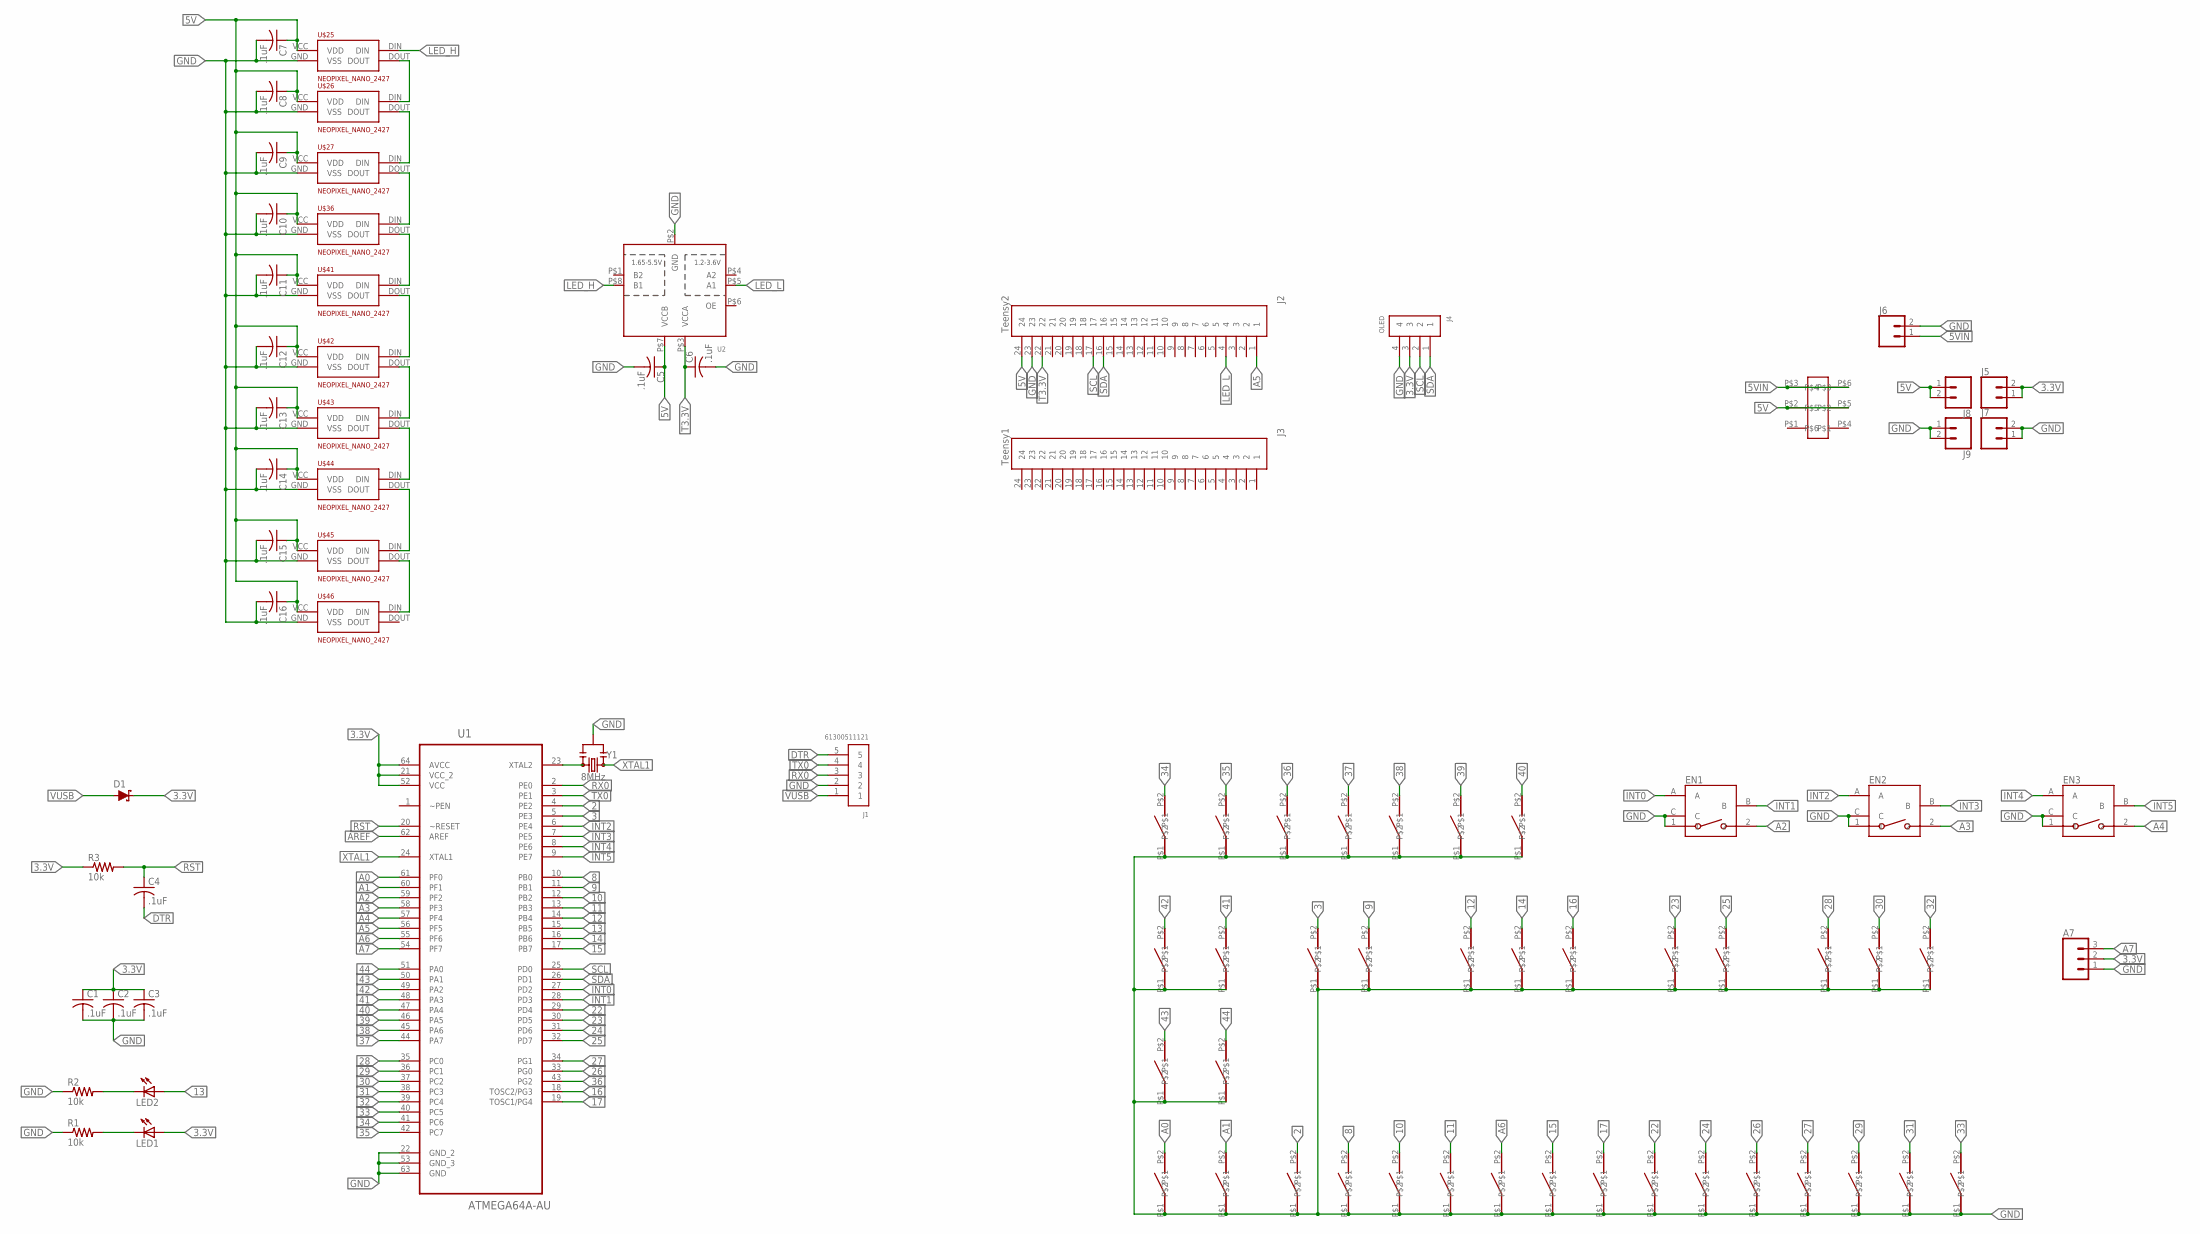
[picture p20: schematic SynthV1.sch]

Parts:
38: BUTTONPAD
A7: CONN_03; 1X03
C1, C2, C3, C4, C5, C6, C7, C8, C9, C10, C11, C12, C13, C14, C15, C16: .1uF; C0805
D1: 0.5A/40V/420mV; SOD-323
EN1, EN2, EN3: PEC11R-4215K-S0024
J1: 61300511121
J2: Teensy2; 61302411121
J3: Teensy1; 61302411121
J4: OLED; 61300411121
J5, J7, J8, J9: CONN_02; 1X02
J6: CONN_02POLAR; MOLEX-1X2
LED1, LED2: LEDCHIPLED_0805; CHIPLED_0805
R1, R2, R3: 10k; R0805
U1: ATMEGA64A-AU; QFP80P1600X1600X120-64N
U2: TXS0102; VFSOP-8
U$1, U$2, U$3, U$4, U$5, U$6, U$7, U$8, U$9, U$10, U$11, U$12, U$13, U$14, U$15, U$16, U$17, U$18, U$19, U$20, U$21, U$22, U$23, U$24, U$28, U$29, U$30, U$31, U$32, U$33, U$34, U$35, U$37, U$38, U$39, U$40: BUTTONPAD
U$25, U$26, U$27, U$36, U$41, U$42, U$43, U$44, U$45, U$46: NEOPIXEL_NANO_2427; SK6805-2427
U$47: JS202011JAQN
Y1: 8MHz; RESONATOR-SMD-3.2X1.3

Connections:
2: U1.4 (PE2), U$1.P$2
3: U1.5 (PE3), U$15.P$2
3.3V: A7.2, C1.1, C2.1, C3.1, D1.C, J4.3, J5.1, J5.2, LED1.A, R3.1, U1.21 (VCC_2), U1.52 (VCC), U1.64 (AVCC)
5V: C5.1, C7.1, C8.1, C9.1, C10.1, C11.1, C12.1, C13.1, C14.1, C15.1, C16.1, J2.24, J8.1, J8.2, U2.P$7 (VCCB), U$25.VCC (VDD), U$26.VCC (VDD), U$27.VCC (VDD), U$36.VCC (VDD), U$41.VCC (VDD), U$42.VCC (VDD), U$43.VCC (VDD), U$44.VCC (VDD), U$45.VCC (VDD), U$46.VCC (VDD), U$47.P$2, U$47.P$5
5VIN: J6.1, U$47.P$3, U$47.P$6
8: U1.10 (PB0), U$2.P$2
9: U1.11 (PB1), U$16.P$2
10: U1.12 (PB2), U$3.P$2
11: U1.13 (PB3), U$4.P$2
12: U1.14 (PB4), U$17.P$2
13: LED2.A, U1.15 (PB5)
14: U1.16 (PB6), U$18.P$2
15: U1.17 (PB7), U$6.P$2
16: U1.18 (TOSC2/PG3), U$19.P$2
17: U1.19 (TOSC1/PG4), U$7.P$2
22: U1.29 (PD4), U$8.P$2
23: U1.30 (PD5), U$20.P$2
24: U1.31 (PD6), U$9.P$2
25: U1.32 (PD7), U$21.P$2
26: U1.33 (PG0), U$10.P$2
27: U1.34 (PG1), U$11.P$2
28: U1.35 (PC0), U$22.P$2
29: U1.36 (PC1), U$12.P$2
30: U1.37 (PC2), U$23.P$2
31: U1.38 (PC3), U$13.P$2
32: U1.39 (PC4), U$24.P$2
33: U1.40 (PC5), U$14.P$2
34: U1.41 (PC6), U$37.P$2
35: U1.42 (PC7), U$38.P$2
36: U1.43 (PG2), U$39.P$2
37: U1.44 (PA7), U$40.P$2
38: 38.P$2, U1.45 (PA6)
39: U1.46 (PA5), U$35.P$2
40: U1.47 (PA4), U$34.P$2
41: U1.48 (PA3), U$33.P$2
42: U1.49 (PA2), U$29.P$2
43: U1.50 (PA1), U$30.P$2
44: U1.51 (PA0), U$31.P$2
A0: U1.61 (PF0), U$32.P$2
A1: U1.60 (PF1), U$28.P$2
A2: EN1.2, U1.59 (PF2)
A3: EN2.2, U1.58 (PF3)
A4: EN3.2, U1.57 (PF4)
A5: J2.1, U1.56 (PF5)
A6: U1.55 (PF6), U$5.P$2
A7: A7.3, U1.54 (PF7)
AREF: U1.62 (AREF)
DTR: C4.2, J1.5
GND: 38.P$1, A7.1, C1.2, C2.2, C3.2, C5.2, C6.2, C7.2, C8.2, C9.2, C10.2, C11.2, C12.2, C13.2, C14.2, C15.2, C16.2, EN1.1, EN1.C, EN2.1, EN2.C, EN3.1, EN3.C, J1.2, J2.23, J4.4, J6.2, J7.1, J7.2, J9.1, J9.2, R1.1, R2.1, U1.22 (GND_2), U1.53 (GND_3), U1.63 (GND), U2.P$2 (GND), U$1.P$1, U$2.P$1, U$3.P$1, U$4.P$1, U$5.P$1, U$6.P$1, U$7.P$1, U$8.P$1, U$9.P$1, U$10.P$1, U$11.P$1, U$12.P$1, U$13.P$1, U$14.P$1, U$15.P$1, U$16.P$1, U$17.P$1, U$18.P$1, U$19.P$1, U$20.P$1, U$21.P$1, U$22.P$1, U$23.P$1, U$24.P$1, U$25.GND (VSS), U$26.GND (VSS), U$27.GND (VSS), U$28.P$1, U$29.P$1, U$30.P$1, U$31.P$1, U$32.P$1, U$33.P$1, U$34.P$1, U$35.P$1, U$36.GND (VSS), U$37.P$1, U$38.P$1, U$39.P$1, U$40.P$1, U$41.GND (VSS), U$42.GND (VSS), U$43.GND (VSS), U$44.GND (VSS), U$45.GND (VSS), U$46.GND (VSS), Y1.2
INT0: EN1.A, U1.27 (PD2)
INT1: EN1.B, U1.28 (PD3)
INT2: EN2.A, U1.6 (PE4)
INT3: EN2.B, U1.7 (PE5)
INT4: EN3.A, U1.8 (PE6)
INT5: EN3.B, U1.9 (PE7)
LED_H: U2.P$8 (B1), U$25.DIN
LED_L: J2.4, U2.P$5 (A1)
unnamed: U1.23 (XTAL2), Y1.3
unnamed: U$25.DOUT, U$26.DIN
unnamed: U$26.DOUT, U$27.DIN
unnamed: U$27.DOUT, U$36.DIN
unnamed: U$36.DOUT, U$41.DIN
unnamed: U$41.DOUT, U$42.DIN
unnamed: U$42.DOUT, U$43.DIN
unnamed: U$43.DOUT, U$44.DIN
unnamed: U$44.DOUT, U$45.DIN
unnamed: LED2.C, R2.2
unnamed: LED1.C, R1.2
unnamed: U$45.DOUT, U$46.DIN
RST: C4.1, R3.2, U1.20 (~RESET)
RX0: J1.3, U1.2 (PE0)
SCL: J2.17, J4.2, U1.25 (PD0)
SDA: J2.16, J4.1, U1.26 (PD1)
T3.3V: C6.1, J2.22, U2.P$3 (VCCA)
TX0: J1.4, U1.3 (PE1)
VUSB: D1.A, J1.1
XTAL1: U1.24 (XTAL1), Y1.1

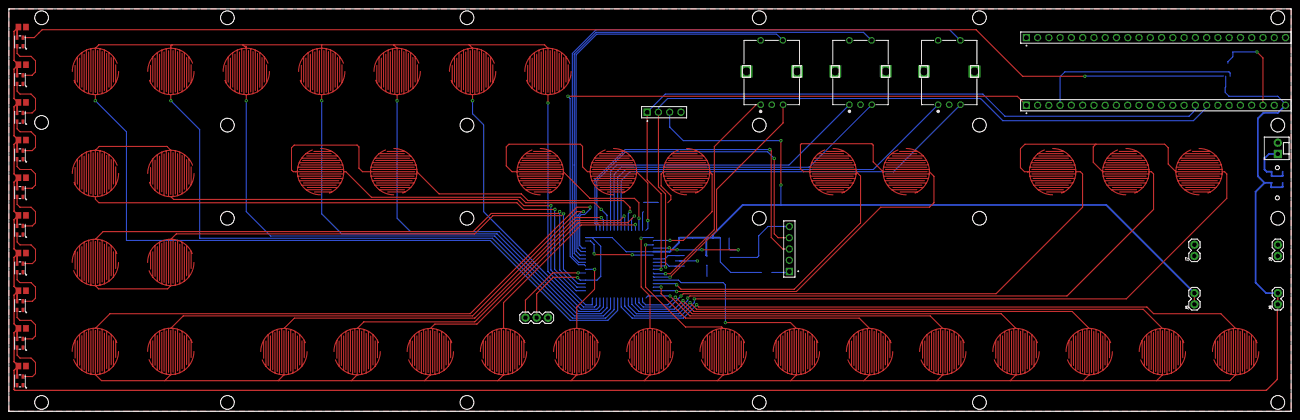
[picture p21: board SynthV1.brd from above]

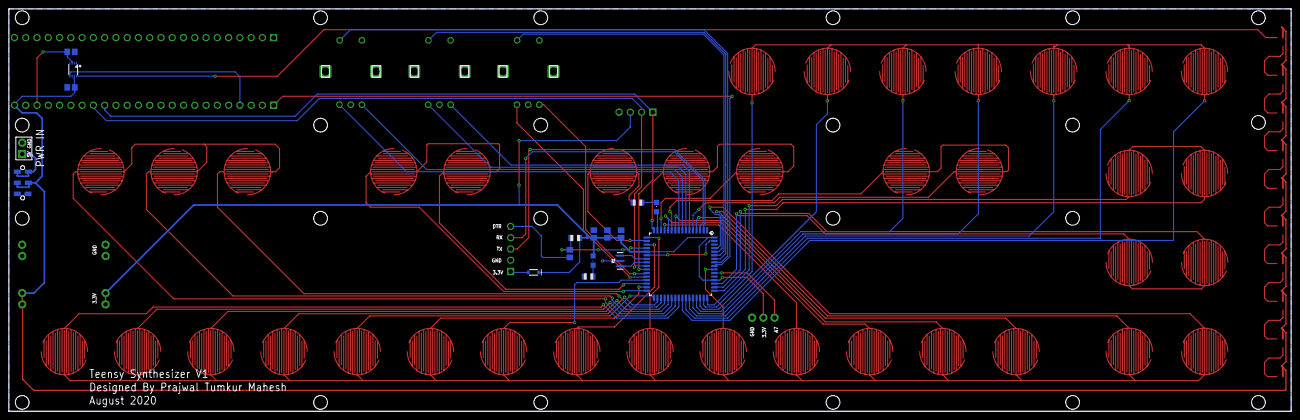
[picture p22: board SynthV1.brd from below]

Board: 2 copper layers, 289.0 x 90.7 mm, 86 parts (16 on the bottom side), 76 nets.

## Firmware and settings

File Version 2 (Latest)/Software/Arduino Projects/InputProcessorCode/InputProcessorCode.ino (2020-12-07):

//
// V2 I2C Input Processor
// Written by Prajwal Tumkur Mahesh
//

#include <Wire.h>

//Indicators for new data
#define LED 7
#define alert_pin 27

// Assign button matrix row pins
#define numRowPins 7
const int rowPins[numRowPins] = {0, 1, 2, 3, 4, 5, 6};

// Assign button matrix column pins
#define  numColPins 7
const int colPins[numColPins] = {8, 9, 10, 11, 12, 13, 14};

int prevState[numRowPins][numColPins] = {0};
int buttonIdx = 0;
int byteIdx = 0;
int bitIdx = 0;

//Quadrature Encoder Parameters
#define NUM_ENC 4
#define ENCA1 18 //Encoder 1 Pin A
#define ENCB1 19 //Encoder 1 Pin B
#define ENCA2 20  //Encoder 2 Pin A
#define ENCB2 21  //Encoder 2 Pin B
#define ENCA3 22 //Encoder 3 Pin A
#define ENCB3 23  //Encoder 3 Pin B
#define ENCA4 24  //Encoder 4 Pin A
#define ENCB4 25  //Encoder 4 Pin B
bool currentState1A;
bool currentState2A;
bool currentState3A;
bool currentState4A;
bool lastState1A;
bool lastState2A;
bool lastState3A;
bool lastState4A;
int8_t counter[NUM_ENC] = {0,0,0,0};

const int encButtonPins[NUM_ENC] = {30,31,32,33};
bool encButtonPrevState[NUM_ENC] = {0,0,0,0};

//Message length in bytes: 1 bit per button+ 2 bits per encoder
//51 bits for 51 buttons + 8 bits for 4 encoders = 58 bits
#define NUM_BYTES 8 
byte buttonStates[NUM_BYTES] = {0,0,0,0,0,0,0,0};

void setup() {
  /*Encoder pins are connected/disconnected to GND
  so they need to be pulled high as a default*/ 
  pinMode(ENCA1,INPUT_PULLUP);
  pinMode(ENCB1,INPUT_PULLUP);
  pinMode(ENCA2,INPUT_PULLUP);
  pinMode(ENCB2,INPUT_PULLUP);
  pinMode(ENCA3,INPUT_PULLUP);
  pinMode(ENCB3,INPUT_PULLUP);
  pinMode(ENCA4,INPUT_PULLUP);
  pinMode(ENCB4,INPUT_PULLUP); 
  
  //Initialize the state of each encoder
  lastState1A = digitalRead(ENCA1);
  lastState2A = digitalRead(ENCA2);
  lastState3A = digitalRead(ENCA3);
  lastState4A = digitalRead(ENCA4);
  
  /*Attach both pins of each encoder to a hardware interrupt to keep track
  of every change*/
  attachInterrupt(ENCA1, updateEncoder1, CHANGE);
  attachInterrupt(ENCB1, updateEncoder1, CHANGE);
  attachInterrupt(ENCA2, updateEncoder2, CHANGE);
  attachInterrupt(ENCB2, updateEncoder2, CHANGE);
  attachInterrupt(ENCA3, updateEncoder3, CHANGE);
  attachInterrupt(ENCB3, updateEncoder3, CHANGE);
  attachInterrupt(ENCA4, updateEncoder4, CHANGE);
  attachInterrupt(ENCB4, updateEncoder4, CHANGE);

  //Initialize Indicators and initialize them to low (nothing to report)
  pinMode(LED, OUTPUT);
  digitalWrite (LED, LOW);
  
  pinMode(alert_pin, OUTPUT);
  digitalWrite (alert_pin, LOW);

  /*All pushbuttons are connected/disconnected to GND
  so they need to be pulled high as a default
  */
  for(int cPin = 0; cPin < numColPins; cPin++)
  {
    pinMode(colPins[cPin], OUTPUT);
    digitalWrite(colPins[cPin], HIGH);
  }
  for(int rPin = 0; rPin < numRowPins; rPin++)
  {
    pinMode(rowPins[rPin], INPUT);
    digitalWrite(rowPins[rPin], HIGH);
  }
  for(int encoderButton = 0; encoderButton < NUM_ENC; encoderButton++)
  {
    pinMode(encButtonPins[encoderButton], INPUT_PULLUP);
  }

  /*Join I2c bus as a slave with address 9
  We're using the alternative I2C pins 16 and 17
  so make sure to add the .swap()
  */
  Wire.swap(1);
  Wire.begin(9);
  //Every time master device requests data, call requestEvent()                
  Wire.onRequest(requestEvent); 
}

void loop() {
/*Iterate over all buttons on the board and update their status in the
    output message only on a rising/falling edge. This way the message is 
    only updated when there is new data.
   */
  // Loop through the columns
  for(int cPin = 0; cPin < numColPins; cPin++)
  {
    //Set the voltage at the current column to LOW/GND
    digitalWrite(colPins[cPin], LOW);
    
    // Loop through the rows
    for(int rPin = 0; rPin < numRowPins; rPin++)
    {
      buttonIdx = 7*rPin+cPin;
      byteIdx = (buttonIdx)/8;
      bitIdx = buttonIdx-(byteIdx*8);
      
      //Check if each switch is pressed. Since the column is set to be LOW,
      // a button that's pressed would also read LOW
      if(digitalRead(rowPins[rPin]) == LOW)
      {
        //Only update the  message if the button state has changed since 
        // last time we checked
        if(prevState[cPin][rPin] == 0)
        {
          //indicate new data
          digitalWrite(LED, HIGH);
          digitalWrite(alert_pin, HIGH); 

          //Flip the corresponding bit to 1 (on)
          bitSet(buttonStates[byteIdx],bitIdx);

          // Update last known state of this switch
          prevState[cPin][rPin] = 1;
        }
      } 
      //Check if each switch is released. Since the column is set to be LOW,
      // a button that's released would read HIGH
      else {
        //Only update the  message if the button state has changed since 
        // last time we checked
        if(prevState[cPin][rPin] == 1)
        {
          //indicate new data
          digitalWrite(LED, HIGH);
          digitalWrite(alert_pin, HIGH);
  
          //Flip the corresponding bit to 0 (off) 
          bitClear(buttonStates[byteIdx],bitIdx);
          
          // Update last known state of this switch
          prevState[cPin][rPin] = 0;
        }
      }
    }
    //Pull the column back up again before we move on
    digitalWrite(colPins[cPin], HIGH);
  }

  
  /*Update message with the state of each encoder.
    Each encoder gets 2 bits to report its status*/
  for (byte e = 0; e < NUM_ENC; e++)  {
    //Read the encoder select button
    if(digitalRead(encButtonPins[e])==LOW)
    {
      if(encButtonPrevState[e] == 0)
      {
          //indicate new data
          digitalWrite(LED, HIGH);
          digitalWrite(alert_pin, HIGH); 

          //Flip the corresponding bit to 1 (on)
          bitSet(buttonStates[6],e);

          // Update last known state of this switch
          encButtonPrevState[e] = 1;
      }
    }
    else {
      if(encButtonPrevState[e] == 1)
      {
          //indicate new data
          digitalWrite(LED, HIGH);
          digitalWrite(alert_pin, HIGH); 

          //Flip the corresponding bit to 0 (off)
          bitClear(buttonStates[6],e);

          // Update last known state of this switch
          encButtonPrevState[e] = 0;
      }
    }
    
    //If Encoder has been incremented...
    if (counter[e] > 0){
      //indicate new data
      digitalWrite(LED, HIGH);
      digitalWrite(alert_pin, HIGH);
      //Flip corresponding bits to 01, or 1 (forward) 
      bitSet(buttonStates[7], e*2);
    }
    //If Encoder has been incremented...
    else if (counter[e] < 0){
      digitalWrite(LED, HIGH);
      digitalWrite(alert_pin, HIGH);
      //Flip corresponding bits to 10, or 2 (backwards)  
      bitSet(buttonStates[7], e*2+1);
    }
    //If nothing has changed with Encoder...
    else{
      //Reset corresponding bits to 00, or 0 
      bitClear(buttonStates[7], e*2);
      bitClear(buttonStates[7], e*2+1);
    }
  }
  delay(1);//delay for sanity
}

//Runs on data request from Teensy
void requestEvent()
{ 
  //Indicate data has been read
  digitalWrite(LED, LOW);
  digitalWrite(alert_pin, LOW);
  //Write 8 bytes of data
  Wire.write(buttonStates,8);
  //Reset encoder counts
  memset(counter, 0, sizeof(counter));
  buttonStates[7] = 0;
}

/*Runs on pin-change interrupt for Encoder 1
  Increments or decrements counter dependng on direction of rotation
 */
void updateEncoder1(){
    currentState1A = digitalRead(ENCA1);
    if (currentState1A != lastState1A  && currentState1A == 1){
      if (digitalRead(ENCB1) != currentState1A) {
        counter[0] ++;
      } else {
        counter[0] --;
      } 
    }
    lastState1A = currentState1A;
}

//Runs on pin-change interrupt for Encoder 2
void updateEncoder2(){
    currentState2A = digitalRead(ENCA2);
    if (currentState2A != lastState2A  && currentState2A == 1){
      if (digitalRead(ENCB2) != currentState2A) {
        counter[1] ++;
      } else {
        counter[1] --;
      } 
    }
    lastState2A = currentState2A;
}

//Runs on pin-change interrupt for Encoder 3
void updateEncoder3(){
    currentState3A = digitalRead(ENCA3);
    if (currentState3A != lastState3A  && currentState3A == 1){
      if (digitalRead(ENCB3) != currentState3A) {
        counter[2] ++;
      } else {
        counter[2] --;
      } 
    }
    lastState3A = currentState3A;
}

//Runs on pin-change interrupt for Encoder 4
void updateEncoder4(){
    currentState4A = digitalRead(ENCA4);
    if (currentState4A != lastState4A  && currentState4A == 1){
      if (digitalRead(ENCB4) != currentState4A) {
        counter[3] ++;
      } else {
        counter[3] --;
      } 
    }
    lastState4A = currentState4A;
}

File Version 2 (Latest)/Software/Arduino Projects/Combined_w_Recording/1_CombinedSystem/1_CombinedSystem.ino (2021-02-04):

//
// Combined Sequencer/Synthesizer/Sampler
// Written by Prajwal Tumkur Mahesh
//
#define USE_SdFat_ 

#include <Audio.h>
#include <Wire.h>
#include <SPI.h>
#include <SerialFlash.h>
#include <WS2812Serial.h>
#include <Si4703_Breakout.h>

#ifdef USE_SdFat_
  #include <SdFat.h>
  SdFat SD; 
#else
  #include <SD.h>
#endif

/*Pin configurations and settings for
 * SSD1351 Color OLED Display
 */
#include <Adafruit_GFX.h>
#include <Adafruit_SSD1351.h>

const int8_t OLED_RESET = -1; 
// Screen dimensions
const byte SCREEN_WIDTH = 128;
const byte SCREEN_HEIGHT = 128;

//Extra pins for SPI
const byte DC_PIN = 40;
const byte CS_PIN = 38;
const byte RST_PIN = 41;

Adafruit_SSD1351 oled = Adafruit_SSD1351(SCREEN_WIDTH, SCREEN_HEIGHT, &SPI1, CS_PIN, DC_PIN, RST_PIN);

// Color definitions
const uint16_t BLACK = 0x0000;
const uint16_t BLUE = 0x001F;
const uint16_t RED = 0xFA20;
const uint16_t GREEN = 0x47E0;
const uint16_t CYAN = 0x07FF;
const uint16_t MAGENTA = 0xF81F;
const uint16_t PURPLE = 0x6011;
const uint16_t YELLOW = 0xFD60;
const uint16_t WHITE = 0xFFFF;
const uint16_t DARKGREY = 0x39C7;
const uint16_t LIGHTGREY = 0x6B6D;
const uint16_t PURERED = 0xF800;
const uint16_t MAROON = 0xBAEB;
const uint16_t DARKGREEN = 0x03A0;
/*Pin configurations and settings for
 * Neopixels
 */
const int numled = 10;
const int pin = 17;

DMAMEM byte drawingMemory[numled*3];         //  3 bytes per LED
DMAMEM byte displayMemory[numled*12]; // 12 bytes per LED

WS2812Serial leds(numled, displayMemory, drawingMemory, pin, WS2812_GRB);

/*Pin configurations and settings for
 * LEDs
 */
const byte enc1LED = 32;
const byte enc2LED = 31;
const byte enc3LED = 30;
const byte enc4LED = 29;

/*Pin configurations SD and Flash
 * Memory
 */
const byte FLASHCHIP_CS_PIN = 6;
const byte SDCARD_MOSI_PIN = 11;  
const byte SDCARD_SCK_PIN = 13;

/*
 * ASDT Output
 */
// GUItool: begin automatically generated code
AudioSynthWaveformDc     env1_dc;        //xy=92.50010299682617,1062.5000228881836
AudioSynthWaveformDc     env2_dc;        //xy=95.50010299682617,1144.5000228881836
AudioMixer4              LFO2_mixer;     //xy=266.5001029968262,956.5000228881836
AudioMixer4              env1_mixer;     //xy=266.5001029968262,1055.5000228881836
AudioMixer4              env2_mixer;     //xy=266.5001029968262,1139.5000228881836
AudioMixer4              LFO1_mixer;     //xy=269.5001029968262,861.5000228881836
AudioSynthWaveformModulated mod_LFO1;       //xy=435.5001029968262,868.5000228881836
AudioSynthWaveformModulated mod_LFO2;       //xy=436.5001029968262,964.5000228881836
AudioEffectEnvelope      mod_env1;       //xy=449.5001029968262,1052.5000228881836
AudioEffectEnvelope      mod_env2;       //xy=452.5001029968262,1139.5000228881836
AudioMixer4              osc2_pitch_mod_mixer; //xy=781.5001029968262,1122.5000228881836
AudioMixer4              osc1_pitch_mod_mixer; //xy=782.5001029968262,899.5000228881836
AudioMixer4              filter_cutoff_mod_mixer; //xy=783.5001029968262,692.5000228881836
AudioSynthWaveformModulated wave2a;         //xy=1031.5001029968262,1035.5000228881836
AudioSynthWaveformModulated wave2b;         //xy=1031.5001029968262,1069.5000228881836
AudioSynthWaveformModulated wave5b;         //xy=1031.5001029968262,1498.5000228881836
AudioSynthWaveformModulated wave1a;         //xy=1034.5001029968262,906.5000228881836
AudioSynthWaveformModulated wave8a;         //xy=1030.5001029968262,1913.5000228881836
AudioSynthWaveformModulated wave3a;         //xy=1033.5001029968262,1173.5000228881836
AudioSynthWaveformModulated wave1b;         //xy=1034.5001029968262,940.5000228881836
AudioSynthWaveformModulated wave8b;         //xy=1030.5001029968262,1947.5000228881836
AudioSynthWaveformModulated wave3b;         //xy=1033.5001029968262,1207.5000228881836
AudioSynthWaveformModulated wave4a;         //xy=1035.5001029968262,1319.5000228881836
AudioSynthWaveformModulated wave4b;         //xy=1035.5001029968262,1353.5000228881836
AudioSynthWaveformModulated wave5a;         //xy=1036.5001029968262,1465.5000228881836
AudioSynthWaveformModulated wave6a;         //xy=1036.5001029968262,1602.5000228881836
AudioSynthWaveformModulated wave6b;         //xy=1036.5001029968262,1636.5000228881836
AudioSynthWaveformModulated wave7a;         //xy=1036.5001029968262,1745.5000228881836
AudioSynthWaveformModulated wave7b;         //xy=1036.5001029968262,1779.5000228881836
AudioSynthNoisePink      noise2;         //xy=1056.5001029968262,1103.5000228881836
AudioSynthNoisePink      noise1;         //xy=1058.5001029968262,974.5000228881836
AudioSynthNoisePink      noise3;         //xy=1059.5001029968262,1241.5000228881836
AudioSynthNoisePink      noise4;         //xy=1060.5001029968262,1387.5000228881836
AudioSynthNoisePink      noise5;         //xy=1061.5001029968262,1532.5000228881836
AudioSynthNoisePink      noise6;         //xy=1067.5001029968262,1669.5000228881836
AudioSynthNoisePink      noise7;         //xy=1067.5001029968262,1812.5000228881836
AudioSynthNoisePink      noise8;         //xy=1072.5001029968262,1980.5000228881836
AudioMixer4              wave1mix;       //xy=1201.5001029968262,956.5000228881836
AudioMixer4              wave2mix;       //xy=1203.5001029968262,1089.5000228881836
AudioMixer4              wave3mix;       //xy=1209.5001029968262,1223.5000228881836
AudioMixer4              wave4mix;       //xy=1212.5001029968262,1371.5000228881836
AudioMixer4              wave5mix;       //xy=1215.5001029968262,1515.5000228881836
AudioMixer4              wave6mix;       //xy=1216.5001029968262,1653.5000228881836
AudioMixer4              wave7mix;       //xy=1221.5001029968262,1797.5000228881836
AudioMixer4              wave8mix;       //xy=1225.5001029968262,1964.5000228881836
AudioEffectEnvelope      synth_envelope_1; //xy=1380.5001029968262,958.5000228881836
AudioEffectEnvelope      synth_envelope_2; //xy=1383.5001029968262,1093.5000228881836
AudioEffectEnvelope      synth_envelope_3; //xy=1389.5001029968262,1227.5000228881836
AudioEffectEnvelope      synth_envelope_4; //xy=1391.5001029968262,1371.5000228881836
AudioEffectEnvelope      synth_envelope_6; //xy=1391.5001029968262,1656.5000228881836
AudioEffectEnvelope      synth_envelope_7; //xy=1395.5001029968262,1804.5000228881836
AudioEffectEnvelope      synth_envelope_8; //xy=1395.5001029968262,1967.5000228881836
AudioEffectEnvelope      synth_envelope_5; //xy=1397.5001029968262,1515.5000228881836
AudioPlaySerialflashRaw  playFlashRaw12; //xy=1402.5001029968262,824.5000228881836
AudioPlaySerialflashRaw  playFlashRaw6;  //xy=1405.5001029968262,617.5000228881836
AudioPlaySerialflashRaw  playFlashRaw11; //xy=1405.5001029968262,791.5000228881836
AudioPlaySerialflashRaw  playFlashRaw1;  //xy=1407.5001029968262,431.5000228881836
AudioPlaySerialflashRaw  playFlashRaw10; //xy=1406.5001029968262,757.5000228881836
AudioPlaySerialflashRaw  playFlashRaw5;  //xy=1408.5001029968262,581.5000228881836
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

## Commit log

2020-08-25 Github upload
    [SynthV1.brd, SynthV1.sch, V1 BOM.csv]
2020-11-25 Added V1 CAD and restructured files
    [SynthV1.brd, SynthV1.sch, V1 BOM.csv]
2020-12-20 Added V2 CAD and EDA files
    [AudioBoard.sch, FullBoard.brd, FullBoard.sch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]
2021-01-14 Added V2.3 Files and BOM
    [AudioBoard.sch, FullBoard.brd, FullBoard.sch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]
2021-01-14 Added STL files for easier 3D printing
    [BigKey.stl, Body1of3.stl, Body2of3.stl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]
2021-01-14 Added PJRC stuff to BOM
    [V2.3BOM.xlsx]
2021-02-06 Updated battery connector on PCB
    [FullBoard.brd, FullBoard.sch]

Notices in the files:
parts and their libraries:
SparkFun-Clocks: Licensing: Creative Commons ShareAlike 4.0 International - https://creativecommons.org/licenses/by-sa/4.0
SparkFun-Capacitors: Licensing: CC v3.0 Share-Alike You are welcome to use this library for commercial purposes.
